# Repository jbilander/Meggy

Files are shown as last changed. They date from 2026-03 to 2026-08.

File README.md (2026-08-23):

# Meggy
A 1MB USB-programmable Kickstart ROM board for Amiga computers with a 42-pin ROM socket (A500+, A600). With a small modification also works in machines with a 40-pin ROM socket such as the A500 rev 6A and B2000.

***

<a href="images/Meggy_revC_pic1.png">
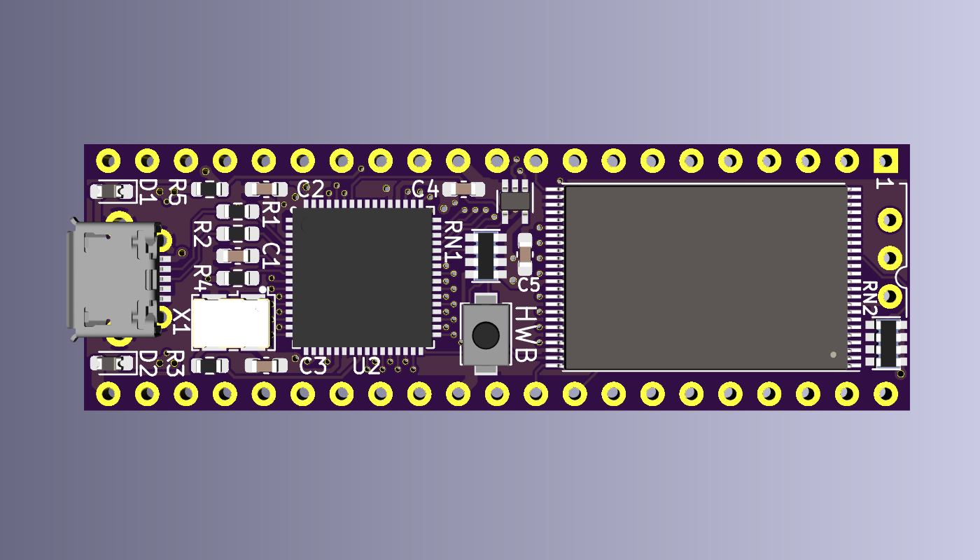
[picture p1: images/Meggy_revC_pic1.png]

</a>
<br />
<a href="images/Meggy_revC_pic2.png">
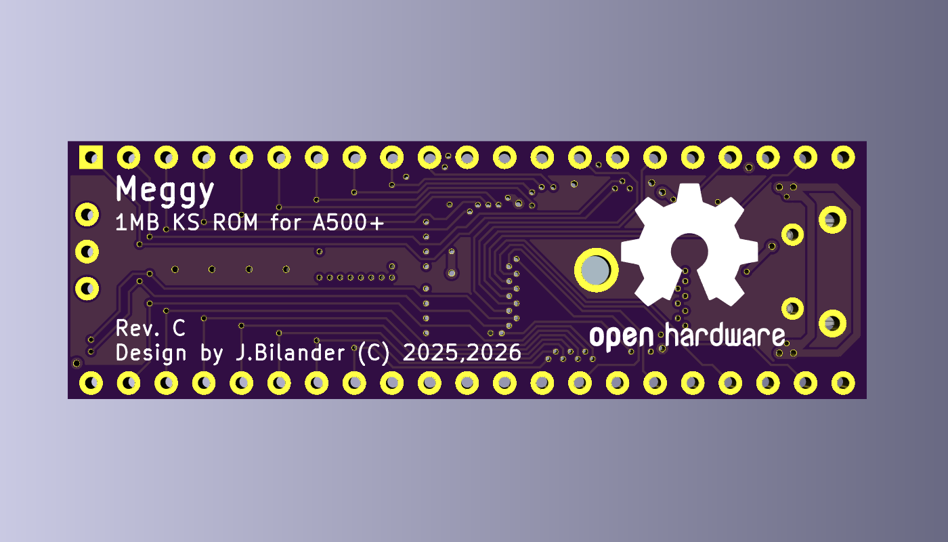
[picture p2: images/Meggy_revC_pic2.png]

</a>
<br />
<a href="images/Meggy_revC_pic3.jpg">
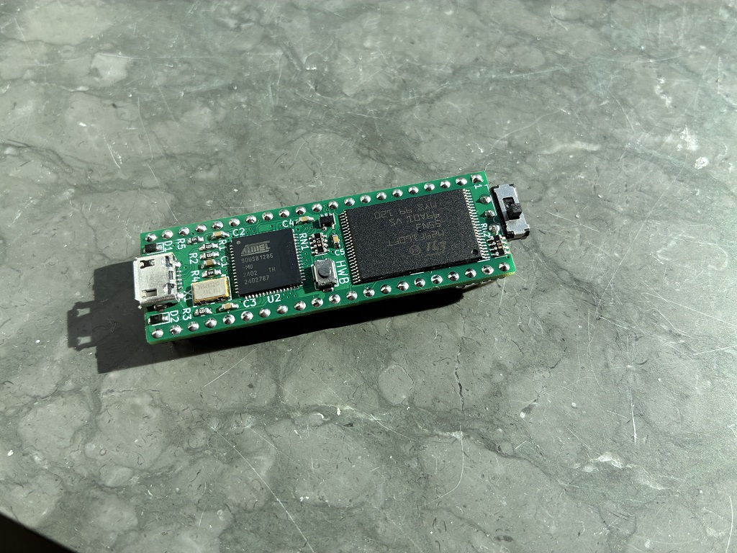
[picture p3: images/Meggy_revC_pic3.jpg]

</a>
<br />
<a href="images/Meggy_revC_pic4.jpg">
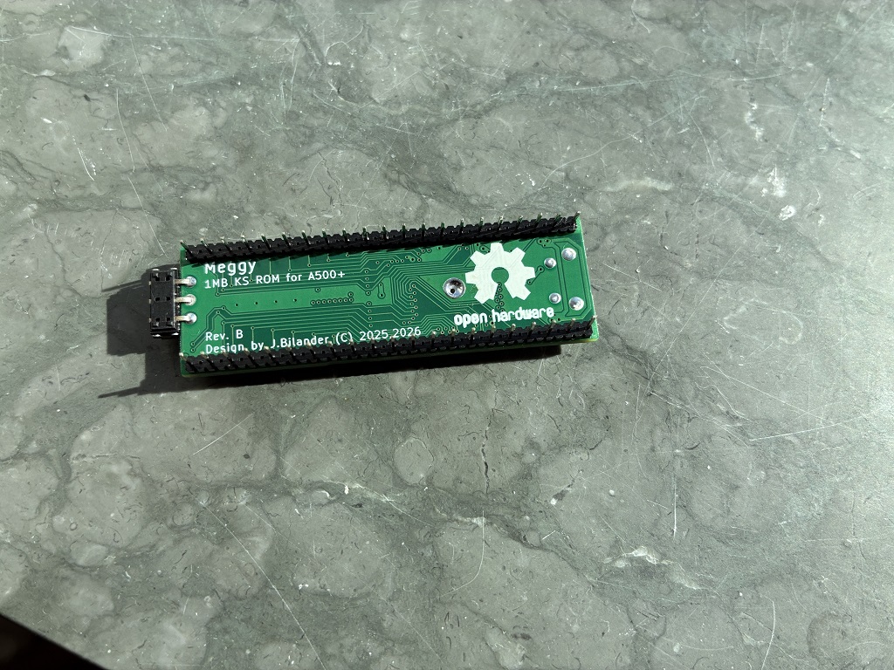
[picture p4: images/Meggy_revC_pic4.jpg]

</a>
<br />
<a href="images/Meggy_revC_installed_in_A500_plus.jpg">
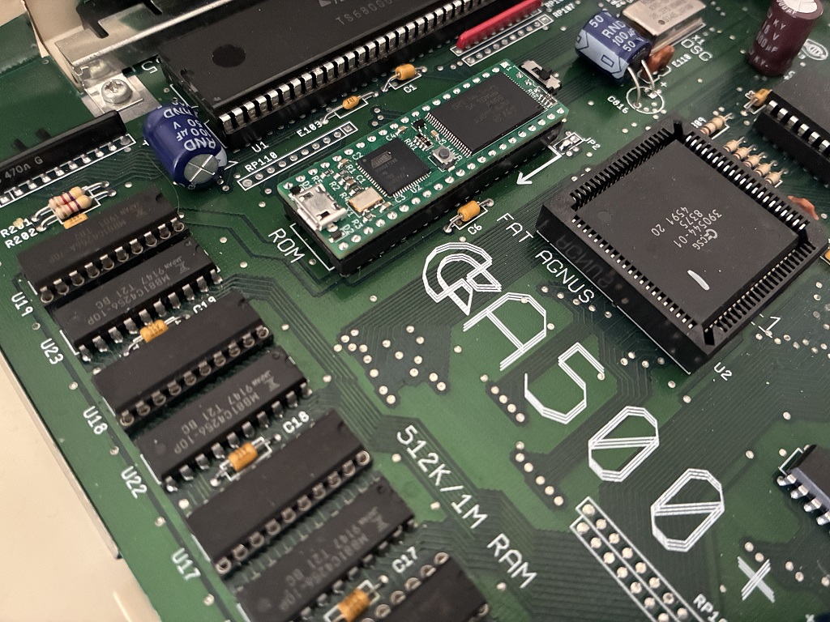
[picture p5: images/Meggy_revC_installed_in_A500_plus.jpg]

</a>
<br />

***

# Bill of Materials — Meggy Rev C

| Ref | Qty | Value | Description | Package | Notes | Mouser |
|-----|-----|---|---|---|---|---|
| U1 | 2 | — | Pin strip 1×21, 2.54mm pitch, 0.4mm square pins | — | <span title="Cut from 1×50 1.27mm pitch strip, remove every other pin to give 2.54mm pitch. Fits Amiga dual-wipe socket better than standard 0.47mm turned pins.">Pin strip info...</span> | [AliExpress example](https://www.aliexpress.com/item/4000979931385.html) |
| U2 | 1 | AT90USB1286-MU | AVR USB microcontroller | QFN-64 | | [556-AT90USB1286-MU](https://www.mouser.com/ProductDetail/556-AT90USB1286-MU) |
| U3 | 1 | M29F160FT55N3E2 | 2MB NOR Flash (top-boot) | TSOP-48 | | [913-M29F160FT55N3E2](https://www.mouser.com/ProductDetail/913-M29F160FT55N3E2) |
| U4 | 1 | 74AHCT1G126GW | Single tristate buffer | SC-70-5 / SOT-353 | <span title="Isolates Gary's /OE signal from the flash chip during USB programming. 10k pull-up on EN keeps buffer enabled by default even with no firmware loaded.">OE isolation...</span> | [771-AHCT1G126GW125](https://www.mouser.com/ProductDetail/771-AHCT1G126GW125) |
| D1, D2 | 2 | CDBU0520 | Schottky diode 0.5A 20V | SOD-523F / 0603 | <span title="Diode-OR between VBUS (USB 5V) and VCC (Amiga 5V). Prevents backfeed between the two supplies. Higher voltage wins.">Power OR...</span> | [750-CDBU0520](https://www.mouser.com/ProductDetail/750-CDBU0520) |
| X1 | 1 | 16 MHz | Crystal oscillator SG5032CCN 16.000000M-HJGA3 | 5×3.2mm SMD | | [732-5032CC16.0HJGA3](https://www.mouser.com/ProductDetail/732-5032CC16.0HJGA3) |
| SW1 | 1 | — | Sunrom Tactile Switch SMD | 3×4×2mm | <span title="Hold HWB button and run --avr-reset to enter DFU bootloader mode for firmware programming.">HWB / DFU entry...</span> | [AliExpress example](https://www.aliexpress.com/item/32855171871.html) |
| J1 | 1 | 10118194-0001LF | Micro USB-B connector, Amphenol FCI, 5-pin | SMD | | [649-10118194-0001LF](https://www.mouser.com/ProductDetail/649-10118194-0001LF) |
| J2 | 1 | MSK12D19 SMD | SMD slide switch, 3-pin, 2.5mm pitch | SMD | <span title="Flash A19 select — open = slot 1 (pull-up), shorted to GND = slot 0. Pins bent to right angle for flush mounting. Alternatively a 3-pin 2.54mm right-angle pin header with external toggle switch.">Flash A19 slot select...</span> | [AliExpress example](https://www.aliexpress.com/item/1005006482584650.html) |
| RN1, RN2 | 2 | 10k | Resistor network 4×10kΩ isolated | 0603×4 (1206) | CAY16-103J4LF | [652-CAY16-103J4LF](https://www.mouser.com/ProductDetail/652-CAY16-103J4LF) |
| R1, R2 | 2 | 22Ω | CR0603-FX-22R0ELF — USB D+/D− series resistors | 0603 | | [652-CR0603FX-22R0ELF](https://www.mouser.com/ProductDetail/652-CR0603FX-22R0ELF) |
| R3 | 1 | 22Ω | CR0603-FX-22R0ELF — Clock series termination | 0603 | | [652-CR0603FX-22R0ELF](https://www.mouser.com/ProductDetail/652-CR0603FX-22R0ELF) |
| R4 | 1 | 100Ω | CR0603-FX-1000ELF — VBUS detection | 0603 | <span title="Series resistor between VBUS_5V and AVR VBUS pin 8 for USB bus voltage detection.">VBUS detect...</span> | [652-CR0603FX-1000ELF](https://www.mouser.com/ProductDetail/652-CR0603FX-1000ELF) |
| R5 | 1 | 10kΩ | CR0603-FX-1002ELF — OE_BUF_EN pull-up | 0603 | <span title="Pull-up to VCC on PE4 (OE_BUF_EN). Keeps the 74AHCT1G126GW buffer enabled by default so Gary controls /OE even with no firmware loaded.">OE_BUF_EN pull-up...</span> | [652-CR0603FX-1002ELF](https://www.mouser.com/ProductDetail/652-CR0603FX-1002ELF) |
| C1 | 1 | 1µF | CL10B105KA8NNND | 0603 | <span title="UCAP filter capacitor on AVR pin 7. Required for the AT90USB1286 internal USB voltage regulator.">UCAP filter...</span> | [187-CL10B105KA8NNND](https://www.mouser.com/ProductDetail/187-CL10B105KA8NNND) |
| C2, C3, C4, C5 | 4 | 100nF | CL10B104KA8NNNC — Bypass decoupling | 0603 | <span title="Bypass decoupling capacitors. Place as close as possible to the VCC pins of U2, U3 and U4.">Bypass decoupling...</span> | [187-CL10B104KA8NNNC](https://www.mouser.com/ProductDetail/187-CL10B104KA8NNNC) |

## Key ICs

**AT90USB1286-MU** — Atmel/Microchip AVR, 128KB flash, native full-speed USB, QFN-64. Runs the Meggy firmware and provides USB bulk transfer for flash programming. DFU bootloader in hardware boot section (no external programmer needed after initial setup).

**M29F160FT55N3E2** — Micron/ST 16Mbit (2MB) NOR flash, top-boot, 55ns, 5V, x16. Stores two 1MB Kickstart image slots selectable via the A19 switch. [Datasheet](https://www.mouser.com/datasheet/3/893/1/M29FxxFT_FB.pdf)

**74AHCT1G126GW** — Single buffer with tristate output (active-high enable). Isolates Gary's /OE signal from the flash chip during USB programming operations. 10k pull-up on EN ensures the buffer is enabled (Amiga in control) by default even with no firmware loaded.

**CDBU0520** — Comchip 0.5A 20V Schottky diode, SOD-523F (0603 footprint). Two used for power OR between VBUS (USB) and VCC (Amiga). Prevents backfeed between the two supplies.

## Power

The board can be powered from either:
- **VBUS** (USB 5V) — when connected to a PC for programming
- **VCC** (Amiga 5V) — when installed in the Amiga

D1 and D2 form a diode-OR, allowing both supplies to coexist safely. The higher voltage wins. Schottky forward drop is approximately 150–200mV at typical operating currents.

***

# Assembly Notes

## Pin Headers (U1)

The two 1×21 pin headers that plug into the Amiga ROM socket are made from standard **1.27 mm pitch pin strips** with every other pin used, giving 21 pins per row at 2.54 mm pitch.

The reason for starting with 1.27 mm strips rather than conventional 2.54 mm strips is pin geometry: 1.27 mm strips have **0.4 mm square pins**, which seat noticeably better in Amiga dual-wipe sockets than the turned (round) pins found on 2.54 mm strips. Turned pins are typically ~0.47 mm in diameter and can spread the socket contacts over time, whereas the slimmer square pins make clean contact without stressing the socket.

### Preparation

Start with two 1.27 mm pitch pin strips, each at least 42 pins long. Using pliers or a similar tool, push every other pin down flush with the top face of the plastic guard — these are the pins that will not be soldered. The result is a strip that alternates between full-length protruding pins and pins that sit flush inside the guard.

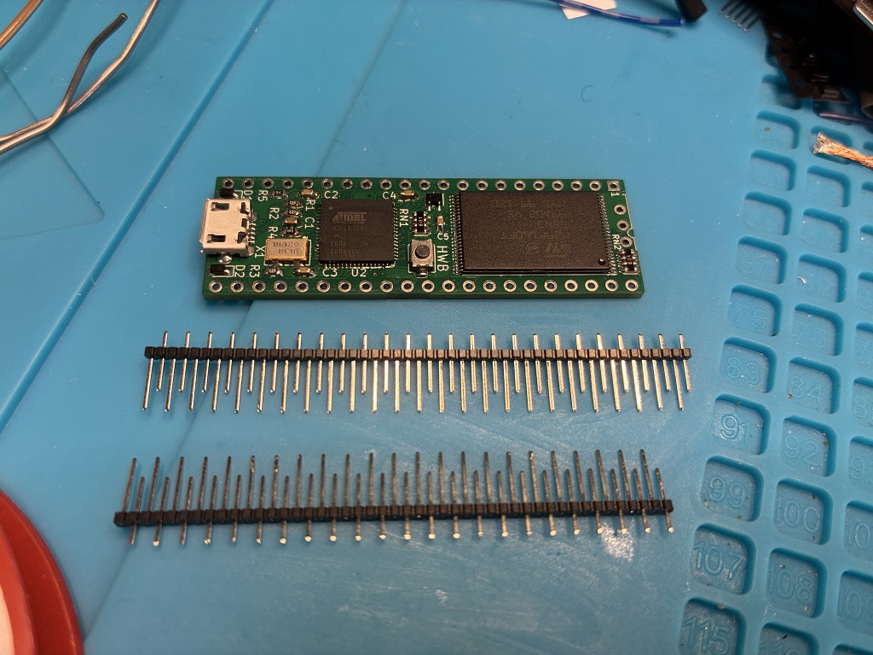
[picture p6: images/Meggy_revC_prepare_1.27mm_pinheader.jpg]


### Self-aligning soldering technique

Place both prepared strips on the work surface with the **plastic guard facing down** and the full-length pins pointing upward. Set the Meggy PCB flat on top so that it rests on the two strips — the full-length pins pass up through the PCB holes from below while the board's own weight holds everything in place.

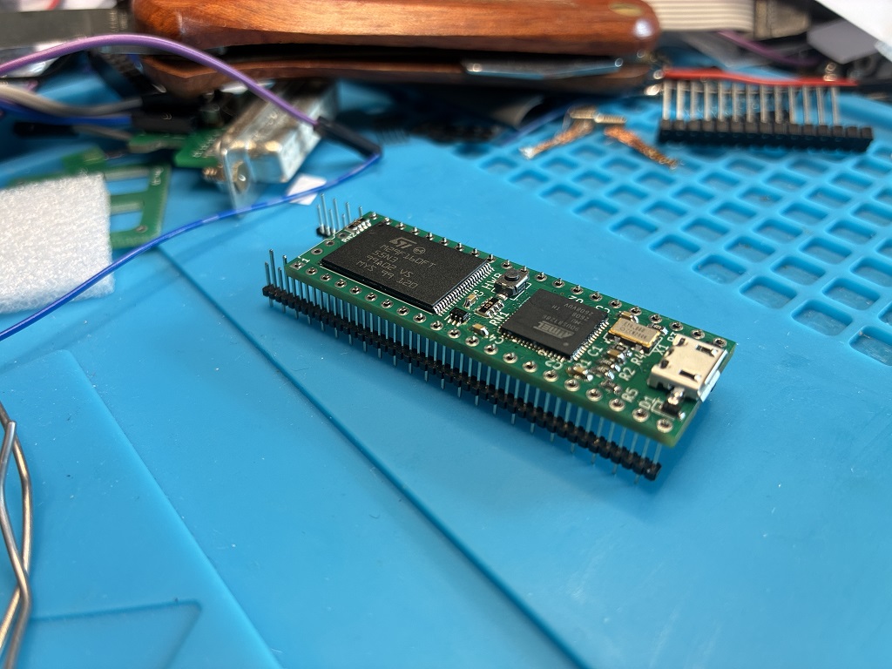
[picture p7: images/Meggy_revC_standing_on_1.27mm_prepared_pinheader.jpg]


Align both strips as straight as possible along the PCB edges, then **tack one corner of each strip** to hold them in position.

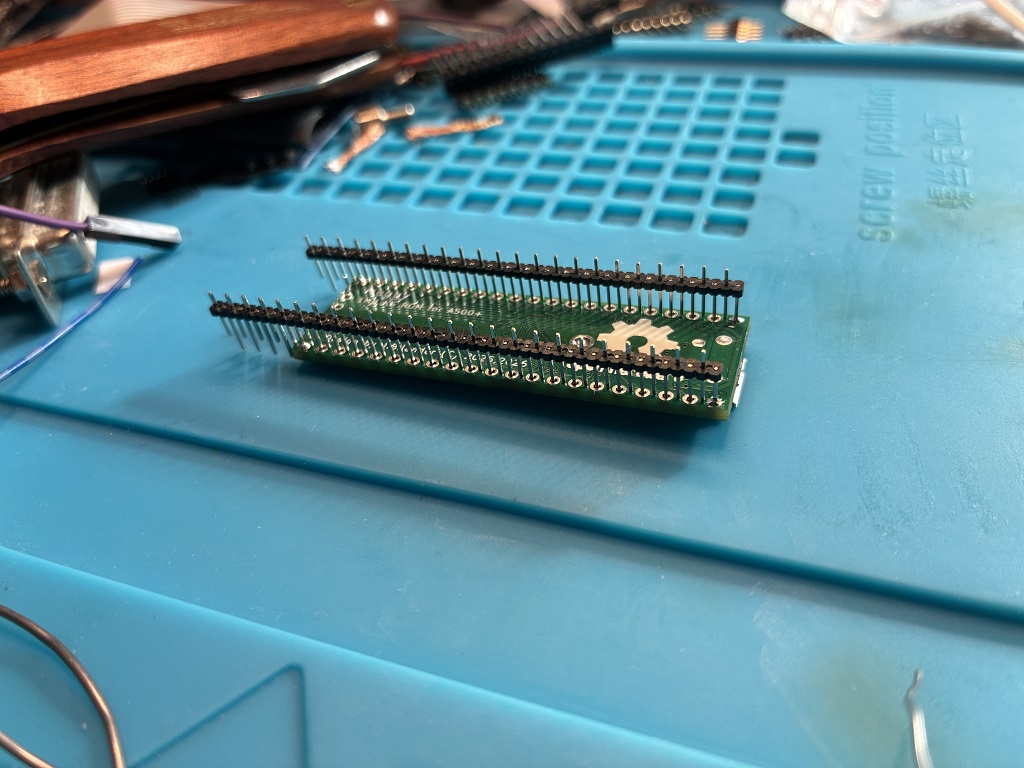
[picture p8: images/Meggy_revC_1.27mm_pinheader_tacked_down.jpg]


At this stage it is still easy to correct misalignment — reflow a tacked corner with the iron, nudge the strip with your finger, and re-tack. Check that the pins protrude consistently above the PCB along the full length of each strip before proceeding. When both strips are correctly aligned, solder all remaining pins from the top side.

After soldering, the underside of the board looks like this:

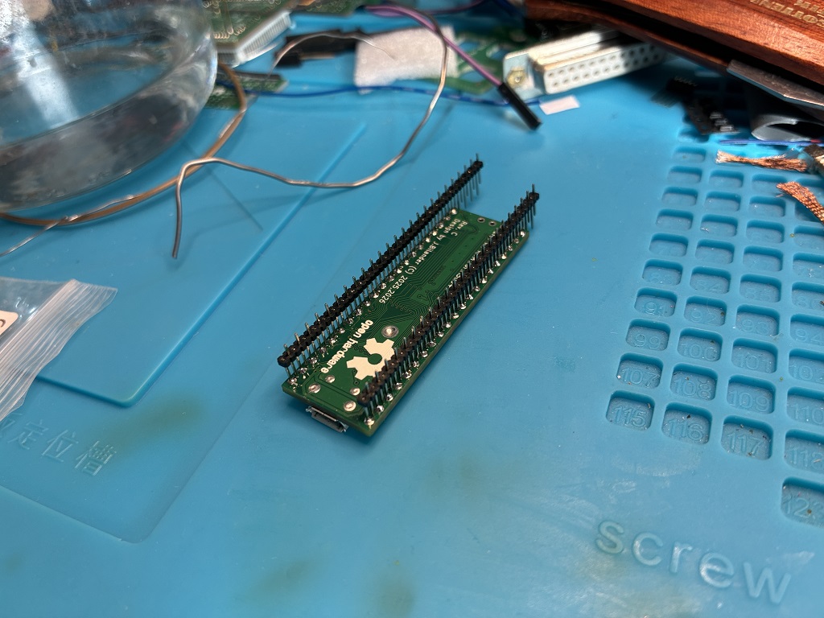
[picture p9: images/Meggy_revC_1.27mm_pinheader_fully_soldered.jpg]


### Removing the plastic guard

With all pins soldered, grip the plastic guard firmly and pull it straight down away from the PCB. The guard separates cleanly by hand — the alternating flush pins are retained inside it and come away with it, leaving only the soldered pins.

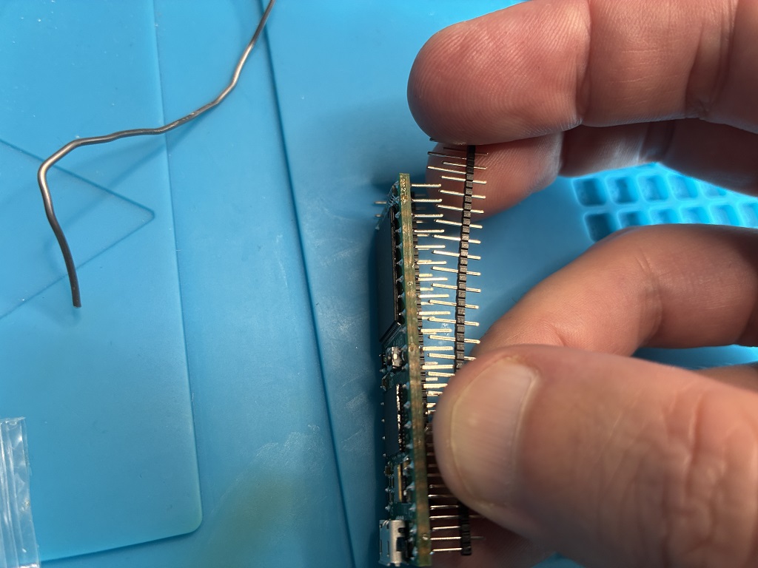
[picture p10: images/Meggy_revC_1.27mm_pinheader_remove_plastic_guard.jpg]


The finished board has two neat rows of evenly spaced pins with no plastic guard to limit insertion depth, allowing Meggy to seat fully into any socket.

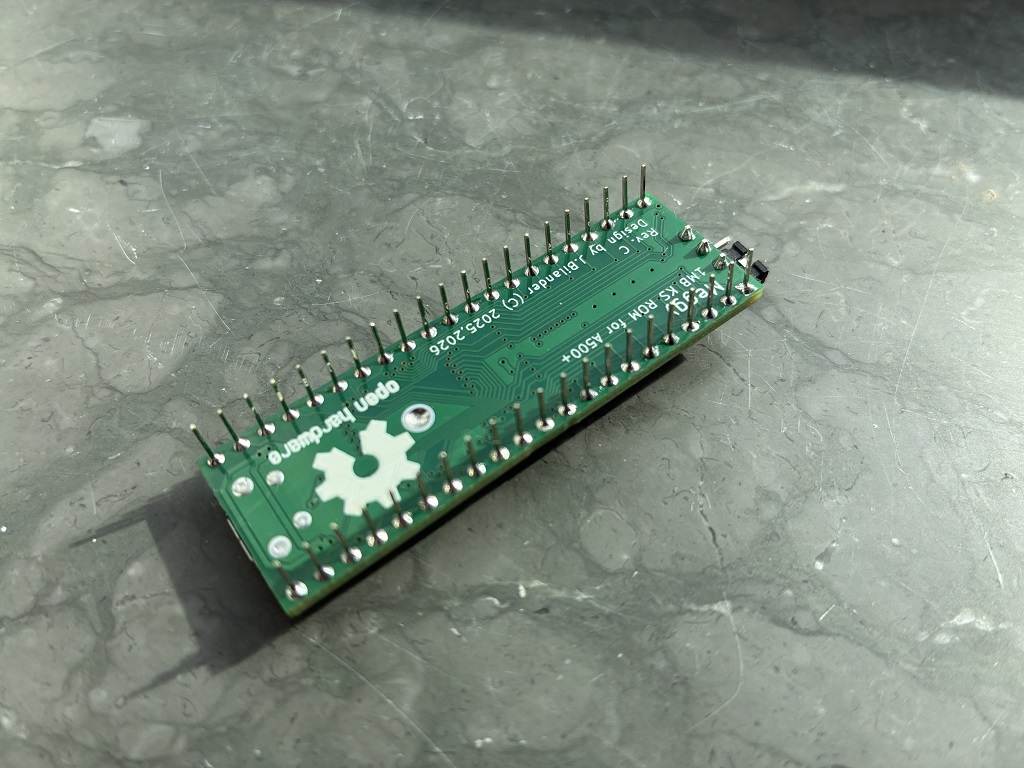
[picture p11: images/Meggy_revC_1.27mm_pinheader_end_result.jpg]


## J2 Slide Switch (MSK12D19) — Bending and Soldering

The MSK12D19 is an SMD slide switch soldered flat on the PCB with its pins bent over and soldered from the top side. To change the Kickstart slot the Amiga needs to be opened. Alternatively J2 can be fitted with a 3-pin 2.54mm right-angle pin header and wired to an external toggle switch mounted somewhere accessible on the Amiga case.

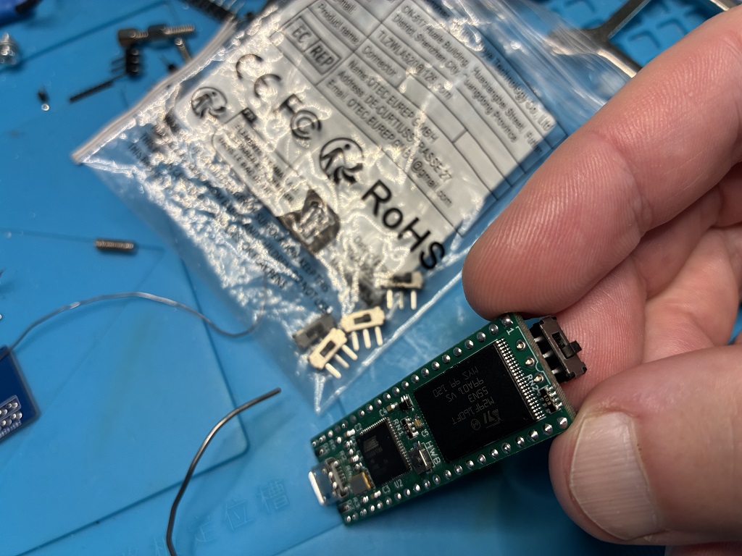
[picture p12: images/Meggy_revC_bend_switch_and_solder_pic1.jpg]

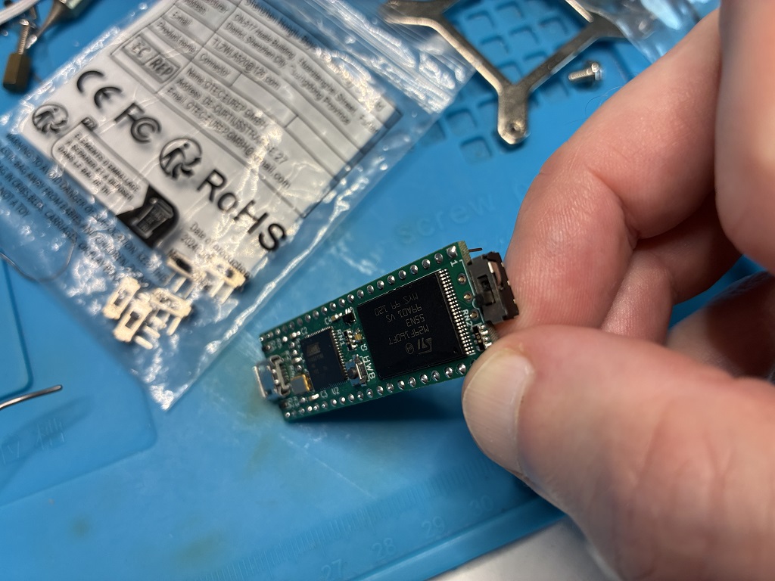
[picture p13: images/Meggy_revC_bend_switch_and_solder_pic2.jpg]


**Steps:**
1. Place the switch into the J2 footprint so the three pins protrude slightly through the top side of the PCB.
2. With your fingers, bend all three pins over flat against the top surface so the switch body ends up level with the board.
3. Apply flux and solder the three pins from the top side with a regular soldering iron.

## AVR Exposed Pad and USB Connector — Soldering Technique

The AT90USB1286-MU QFN-64 has a large exposed thermal pad on the underside that must be soldered to the GND pour for reliable operation. The Micro USB connector also has through-hole anchor pins. Both benefit from using a desoldering station with good thermal mass — a ZD915 or similar works well for this.

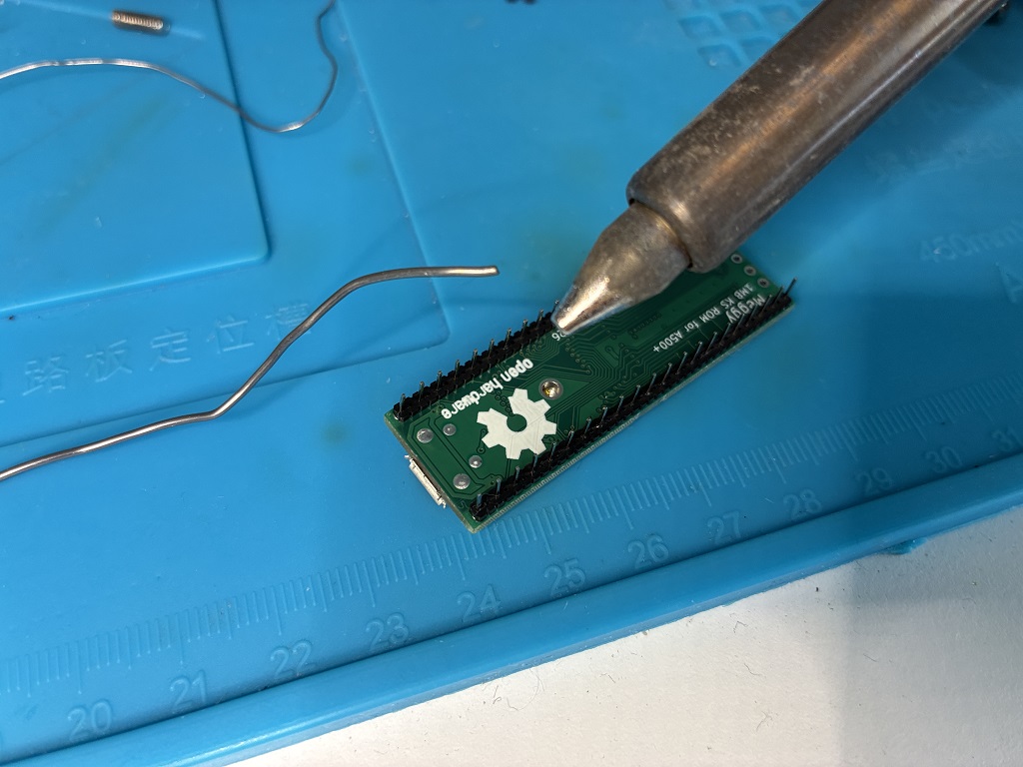
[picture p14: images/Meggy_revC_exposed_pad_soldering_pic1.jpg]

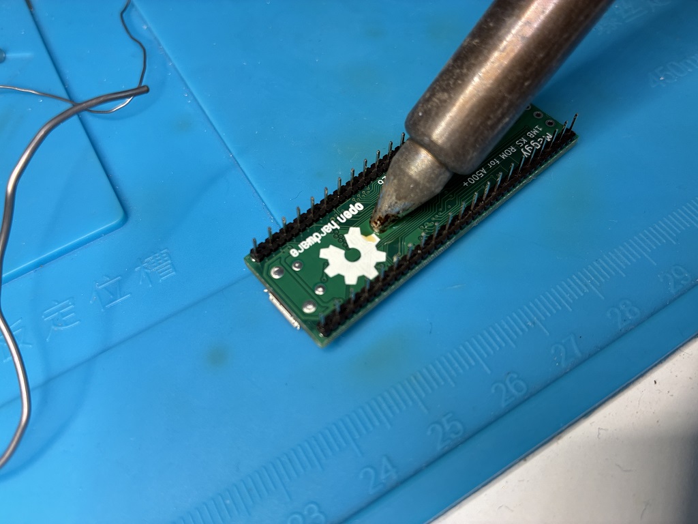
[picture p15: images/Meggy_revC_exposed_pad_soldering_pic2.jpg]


**AVR exposed pad:**
1. Apply flux into the PCB via hole that sits directly under the exposed pad.
2. Place the desoldering nozzle against the hole from the underside and feed solder wire into the nozzle, holding for 3–4 seconds. The thermal mass of the station heats the via quickly and the solder wicks up through the hole making solid contact with the exposed pad above.

**USB connector through-hole anchor pins:**
1. Apply flux on both sides of the PCB at each anchor pin hole.
2. Solder from one side — applying flux to the opposite side encourages a clean bleed-through joint, giving a solid mechanical connection.

***

# Windows Setup

Meggy uses two distinct USB personalities:

| Mode | USB ID | When active | Driver needed |
|---|---|---|---|
| **DFU bootloader** | 03EB:2FFB | No firmware, or HWB held during power-up | libusb-win32 (via Zadig) |
| **Flash programmer** | 03EB:2044 | Normal firmware operation | WinUSB (via Zadig) |

Both drivers are installed with [Zadig](https://zadig.akeo.ie). The steps below cover the full setup from a fresh Windows machine.

## Prerequisites

- **Arduino IDE 1.8.x** — provides `avrdude.exe` used by `flash.bat` to program the AVR firmware. Tested with Arduino IDE 1.8.16. Newer versions of Arduino IDE (2.x) install avrdude in a different location and may require editing the `AVR_PATH` variable in `build.bat` and `flash.bat`. Download from [arduino.cc](https://www.arduino.cc/en/software).
- **Python 3.x** — required for `meggy_flash.py` (see Step 1 below).

---

## Step 1 — Install Python

Download Python 3.x (64-bit) from [python.org](https://www.python.org/downloads/) and run the installer.

**Important:** tick **"Add python.exe to PATH"** before clicking Install Now.

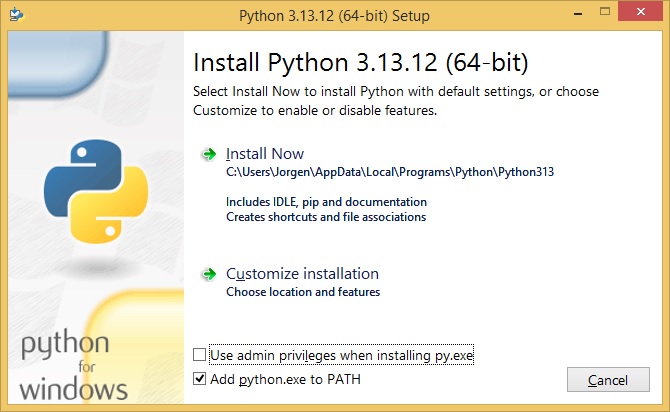
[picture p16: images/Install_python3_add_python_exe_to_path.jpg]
Install Python — tick Add python.exe to PATH


---

## Step 2 — Install PyUSB

Open a Command Prompt and run:

```
pip install pyusb
```

If you run `meggy_flash.py` before installing PyUSB you will see the reminder message shown below — just run the pip command and try again.

PyUSB not found — pip install pyusb

---

## Step 3 — Install libusb-1.0.dll

PyUSB on Windows requires `libusb-1.0.dll` to be present. Download the latest libusb release from [libusb.info](https://libusb.info), open the archive with 7-Zip or similar, and copy `libusb-1.0.dll` from the `VS2015\MS64\dll\` folder into `C:\Windows\System32`.

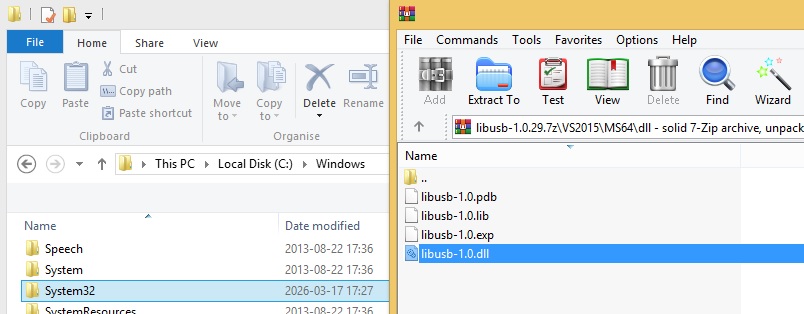
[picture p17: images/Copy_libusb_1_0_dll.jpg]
Copy libusb-1.0.dll to C:\Windows\System32


---

## Step 4 — Install Zadig

Download [Zadig](https://zadig.akeo.ie) (a single portable `.exe`, no installation required) and save it somewhere convenient.

zadig-2.9.exe in Downloads folder

---

## Step 5 — Install the DFU driver (libusb-win32)

This driver is used when Meggy is in DFU bootloader mode for **firmware** programming.

**Put Meggy into DFU mode:**

A freshly soldered board with no firmware loaded will enter DFU mode automatically on power-up — just plug in the USB cable and the device enumerates as **AT90USB128 DFU** without any button press needed.

If firmware is already installed, hold the HWB button and run `python meggy_flash.py --avr-reset` (see the Firmware Programming section below).

Windows will detect a new device. Without the driver it appears as **AT90USB128 DFU** under *Other devices* in Device Manager with a warning icon.

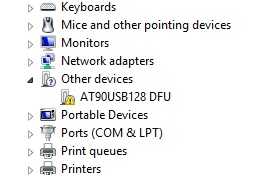
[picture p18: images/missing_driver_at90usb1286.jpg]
AT90USB128 DFU listed as unknown device


Open Zadig. The device **AT90USB128 DFU** (USB ID `03EB 2FFB`) should appear in the dropdown. Make sure the target driver on the right is set to **libusb-win32**, then click **Install Driver**.

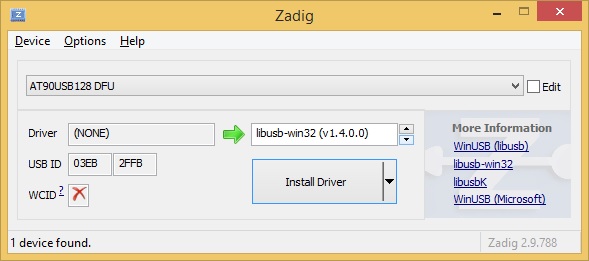
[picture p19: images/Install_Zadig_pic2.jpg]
Zadig — installing driver progress bar


Zadig installs the driver (this takes a few seconds).

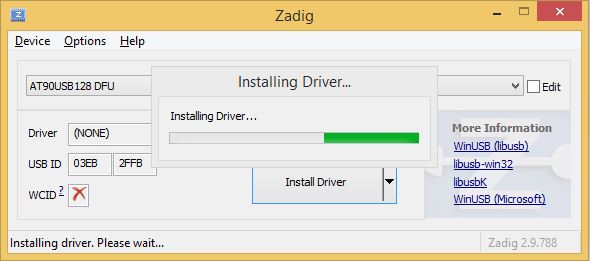
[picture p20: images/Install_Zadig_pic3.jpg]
Zadig — driver installed successfully


When complete, Zadig reports **"The driver was installed successfully."**

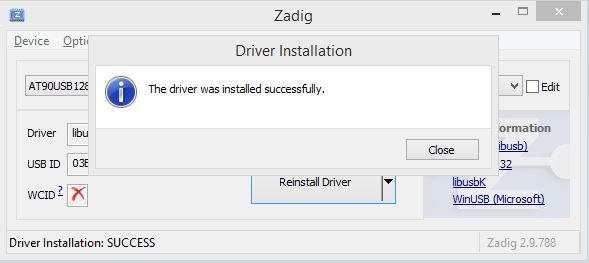
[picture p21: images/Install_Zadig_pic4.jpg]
Device Manager — AT90USB128 DFU under libusb-win32 devices


Device Manager now shows **AT90USB128 DFU** under *libusb-win32 devices* — no warning icon.

Zadig — select libusb-win32 for AT90USB128 DFU

---

## Step 6 — Install the Flash Programmer driver (WinUSB)

This driver is used during normal operation when Meggy presents itself as the **Meggy Flash Programmer** for **NOR flash** programming.

Unplug Meggy and plug it back in without holding HWB so it boots into normal firmware mode. Windows detects it as **Meggy Flash Programmer** under *Other devices*. If you try to install the driver via Windows Update or Device Manager directly, Windows will refuse because the INF lacks a digital signature.

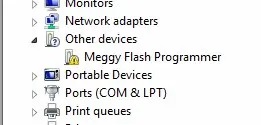
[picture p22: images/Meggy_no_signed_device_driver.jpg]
Meggy Flash Programmer — no signed driver error

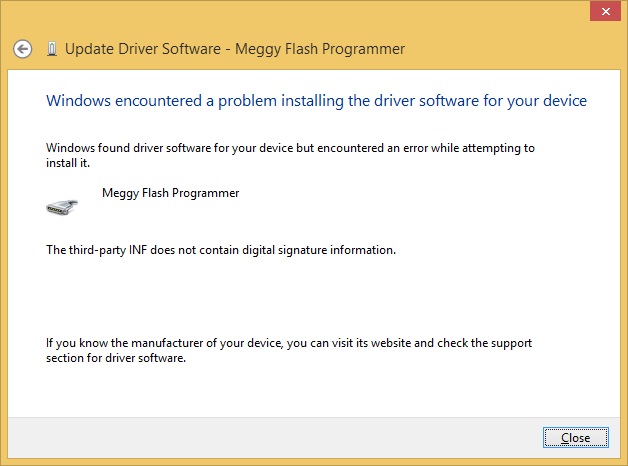
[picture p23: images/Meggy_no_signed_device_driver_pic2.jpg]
Windows driver signature error dialog


Use Zadig instead. Select **Meggy Flash Programmer** (USB ID `03EB 2044`) from the dropdown and confirm the target driver on the right is **WinUSB**, then click **Install Driver**.

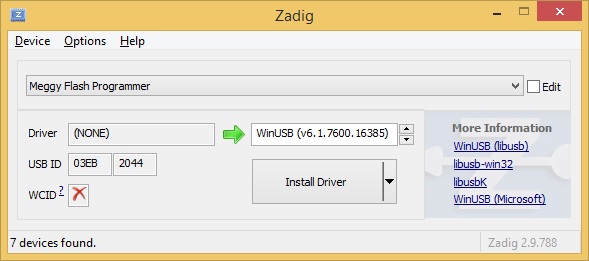
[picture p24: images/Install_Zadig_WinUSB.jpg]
Zadig — select WinUSB for Meggy Flash Programmer


Zadig installs the driver and reports success.

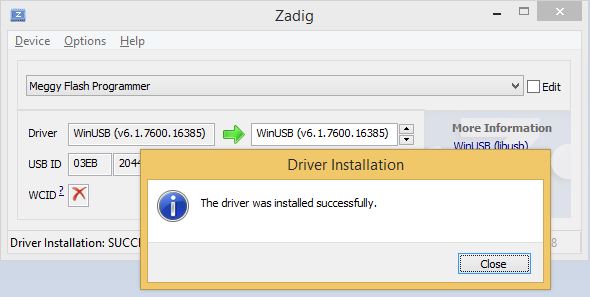
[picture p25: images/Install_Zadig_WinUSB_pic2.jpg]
Zadig — WinUSB driver installed successfully


Device Manager now shows **Meggy Flash Programmer** under *Universal Serial Bus devices*.

Device Manager — Meggy Flash Programmer under Universal Serial Bus devices

Both drivers are now in place and setup is complete.

***

# Firmware Programming

The AT90USB1286 ships with a USB DFU bootloader burned into the hardware boot section. This bootloader cannot be erased, so no external programmer is ever required after the chip is soldered.

## Entering DFU Mode

A freshly soldered board with no firmware loaded will enter DFU mode automatically on power-up — just plug in USB and it enumerates as **AT90USB128 DFU** (USB ID `03EB:2FFB`) without any button press needed.

If firmware is already installed:

**Preferred method** (firmware running):
1. Hold the HWB button.
2. Run `python meggy_flash.py --avr-reset`
3. Release HWB once avrdude connects.

The `--avr-reset` command triggers a hardware reset via the PE5→RESET connection, which causes the bootloader to check HWB and enter DFU mode. This is the only way to enter DFU mode when firmware is already running on Rev C.

## Building the Firmware

From the `firmware/` folder, run:

```bat
build.bat
```

This compiles the firmware and produces `meggy_firmware.hex`. LUFA must be cloned into the `firmware/LUFA/` subfolder first:

```bat
cd firmware
git clone https://github.com/abcminiuser/lufa LUFA
```

## Flashing the Firmware (Windows)

From the `firmware/` folder, run:

```bat
flash.bat
```

This calls `avrdude` with the `flip1` programmer protocol targeting the AT90USB1286 DFU bootloader and handles firmware upload and verification automatically. Some harmless warnings about fuse bits not being accessible via FLIP are expected and can be ignored.

After flashing, power cycle the board to return to normal firmware mode:
- **Standalone:** unplug and replug USB.
- **Installed in Amiga:** disconnect USB and Amiga power, then reconnect.

## Flashing the Firmware (Linux / macOS)

Install `dfu-programmer` via your package manager, then:

```sh
dfu-programmer at90usb1286 erase
dfu-programmer at90usb1286 flash meggy_firmware.hex
dfu-programmer at90usb1286 start
```

The `start` command reboots the AVR automatically into firmware mode. Meggy will enumerate as **Meggy Flash Programmer** (USB ID `03EB:2044`), ready for NOR flash programming.

***

# NOR Flash Programming

With the firmware running and the WinUSB driver installed, use `meggy_flash.py` from the `firmware/` folder to read and write the M29F160 NOR flash over USB.

**Important:** set the J2 switch to the desired slot **before** running any programming commands. The physical switch position determines which 1MB half of the flash chip is accessed — the software always programs whichever slot the switch currently selects.

**Power and bus contention note:** the safest way to program Meggy is standalone — removed from the Amiga socket and powered from USB only. This avoids both power and bus contention issues entirely.

Programming while installed in the Amiga with the Amiga powered off would be equally convenient, but unfortunately does not work reliably. The unpowered chips on the motherboard (CPU, Gary, RAM) draw current through their protection diodes from Meggy's bus lines, dragging down the supply voltage during programming and causing timeouts at around 12% through the image.

With the Amiga powered on, programming works reliably in practice, but there is a theoretical bus contention risk: the address and data lines are shared directly between the AVR and the Amiga bus, and the CPU may drive the same lines simultaneously during any bus cycle. The /OE isolation provided by U4 (74AHCT1G126GW) prevents Gary from asserting /OE on the flash, so the flash will not drive data lines in response to Amiga read cycles — if the CPU attempts a ROM read it simply reads floating lines and stalls or crashes harmlessly. The flash being in read mode between programming operations is the safer state; the contention risk is highest during the brief /WE pulse when the AVR actively drives data lines. In practice the contention window is very brief and programming completes without errors, but for critical or repeated programming operations removing the board first is the cleanest approach.

## Quick-start

```sh
# Identify the device and flash chip
python meggy_flash.py --identify

# Write a Kickstart image (set J2 switch to desired slot first)
python meggy_flash.py --write kick31.rom

# Write a Kickstart image with 16-bit byte-swap applied (for unswapped ROM files)
python meggy_flash.py --write kick31.rom --swap

# Read back the current slot for verification
python meggy_flash.py --read-slot readback.bin

# Verify flash contents against a ROM file
python meggy_flash.py --verify kick31.rom

# Erase the current slot
python meggy_flash.py --erase

# Reset the AVR into DFU mode (hold HWB button while executing this command)
python meggy_flash.py --avr-reset
```

***

# Using Meggy in a 40-pin ROM Socket (A500 rev 6A, A2000)

Meggy is designed for the 42-pin ROM socket found in the A500+ and A600. With a small modification it also works in machines with a 40-pin ROM socket such as the A500 rev 6A and A2000, which lack pin 1 (A19) and pin 42 (A20). The following has been tested on an A500 rev 6A.

## Modifications Required

**J2 slot switch — replace MSK12D19 with a pin header:**
On the A500 rev 6A the can oscillator on the motherboard sits directly below where the MSK12D19 slide switch would be, making it impossible to fit. Desolder the MSK12D19 from J2 and replace it with a standard 3-pin 2.54mm right-angle pin header. A standard 2.54mm jumper shunt can then be used to select the slot, and the right-angle header clears the can oscillator without conflict.

**Remove the plastic guards from the pin strips (if not already done):**
Single-wipe sockets have shallower contact depth than dual-wipe sockets. The plastic guard on the pin strips adds height that may prevent Meggy from seating fully into the socket. If you followed the recommended assembly method in the Pin Headers section above the guards will already have been removed as the final step of soldering — no further action is needed. If the guards are still present, grip each one firmly and pull it straight down away from the PCB; it should separate cleanly by hand, bringing the alternating unused pins with it.

**A19 jumper wire:**
The 42-pin socket has pin 1 carrying the CPU A19 signal, which selects which 512KB bank of the Kickstart the CPU is accessing. The 40-pin socket does not have this pin, so Meggy's pin 1 will hang over the edge of the socket with no connection. A short jumper wire must be soldered from Meggy's pin 1 to the A19 signal on the motherboard.

On the A500 rev 6A the A19 signal is conveniently available at solder jumper JP2 on the motherboard, which is only about 1cm from where Meggy's pin 1 overhangs the socket — making it a very short and clean connection. Alternatively A19 can be found at pin 47 of the 68000 CPU (DIP-64 package).

## Compatibility Notes

- Tested and working on A500 rev 6A with Kickstart 3.1.4 (512KB duplicated) and 1MB capitoline image
- The single-wipe socket on the A500 rev 6A gives less firm contact than a dual-wipe socket — replacing it with a good quality dual-wipe socket is recommended for long term reliability
- The 1MB capitoline extended ROM image works correctly — icon.library 45.22 and workbench.library 45.194 load from extended ROM at $E00000 even when booting an older Workbench disk

## Photos

Meggy with plastic guards still on the pin strips:

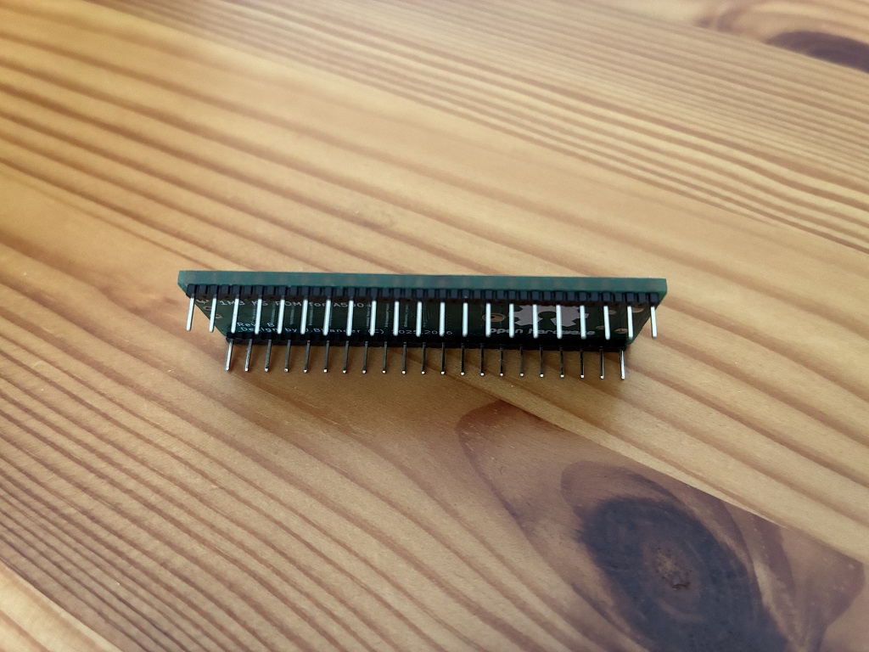
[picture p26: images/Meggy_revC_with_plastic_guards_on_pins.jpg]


Plastic guards removed and laid next to the board. Also visible: the 3-pin right-angle header fitted to J2 in place of the MSK12D19, with a standard jumper shunt for slot selection:

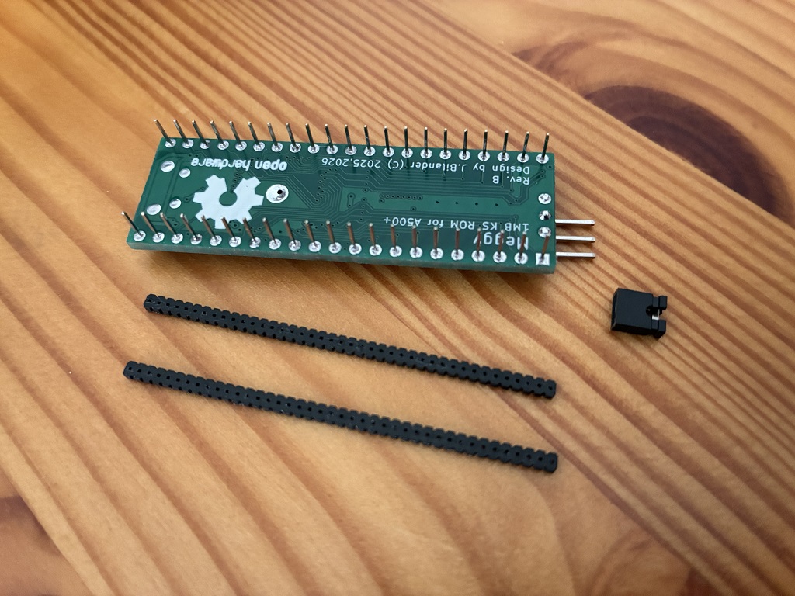
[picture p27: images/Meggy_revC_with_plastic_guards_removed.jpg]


Meggy installed in the A500 rev 6A 40-pin socket. Pin 1 hangs over the left edge of the socket with no connection yet. The can oscillator is visible to the left — this is why the MSK12D19 had to be replaced with a pin header. JP2 carrying the A19 signal is visible on the motherboard just to the left of Meggy's overhanging pin 1:

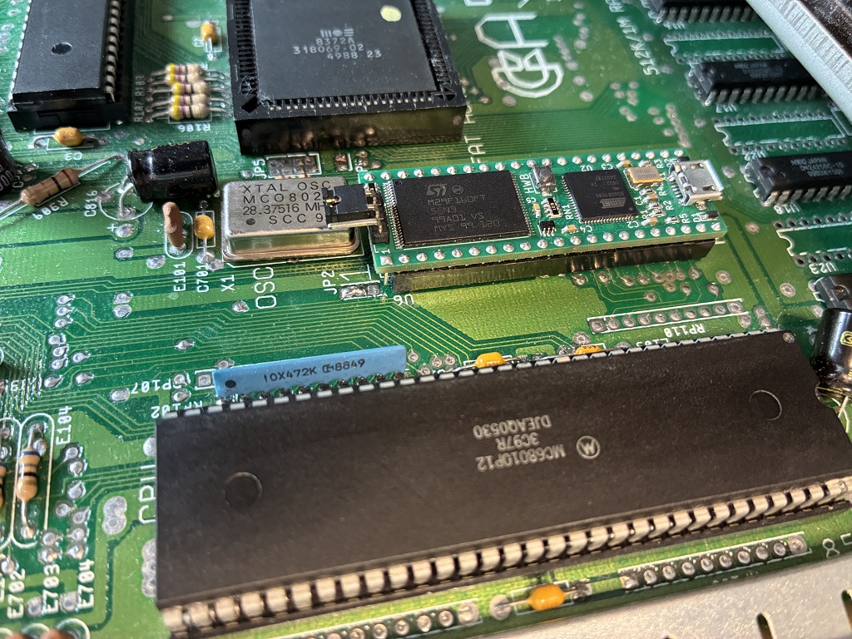
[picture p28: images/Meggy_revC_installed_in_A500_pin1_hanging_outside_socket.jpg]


Meggy installed with the A19 jumper wire connected. Yellow test clip leads run from Meggy's overhanging pin 1 to the A19 signal on the 68000 CPU. JP2 on the motherboard — visible just to the left of Meggy — provides a much neater and closer connection point for a permanent wire:

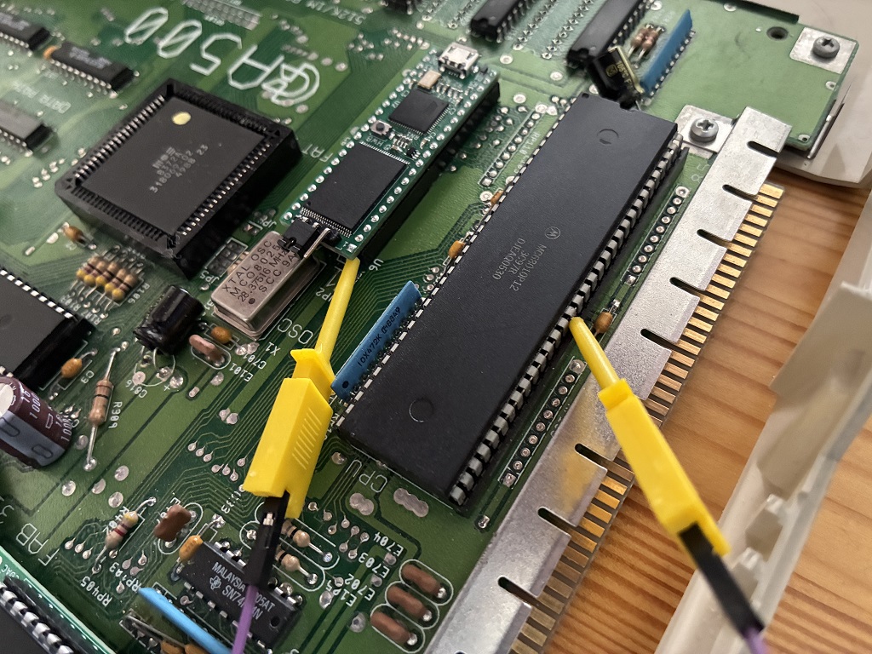
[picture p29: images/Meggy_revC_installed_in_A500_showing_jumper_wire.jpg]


DiagROM V1.2.1 running on the A500 rev 6A — CPU 68000, 1024kB chip RAM confirmed:

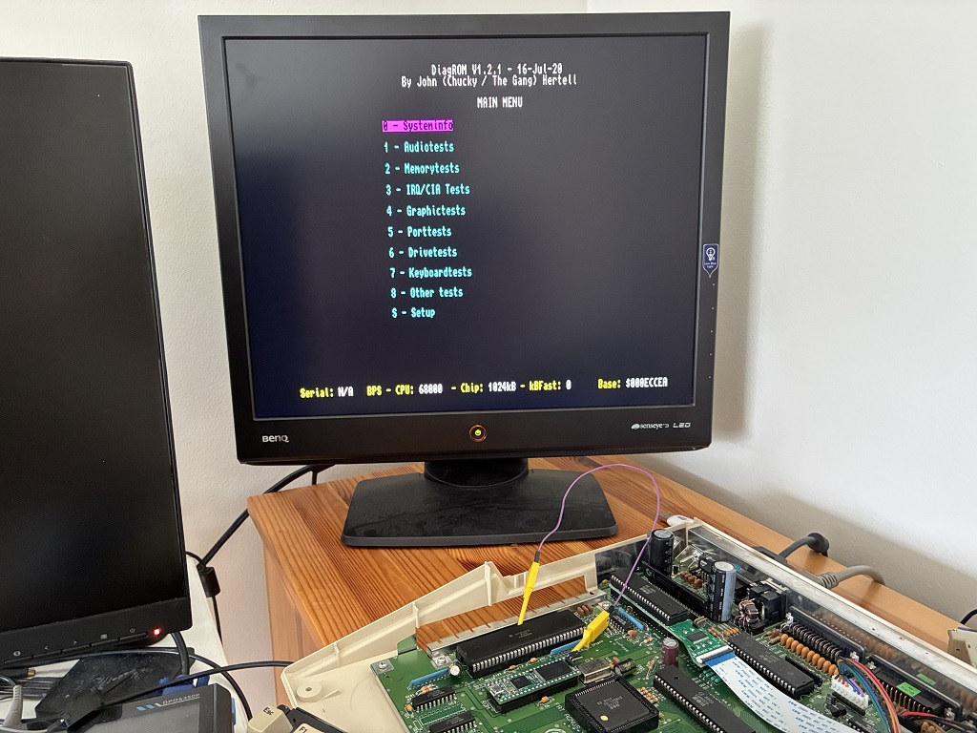
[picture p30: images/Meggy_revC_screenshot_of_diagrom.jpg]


Workbench 1.3 (34.34) booting under Kickstart 3.1.4 (46.143) on the A500 rev 6A. icon.library version 45.22 and workbench.library version 45.194 are both loading from the extended ROM at $E00000 — confirming the full 1MB capitoline image works correctly on the A500 rev 6A:

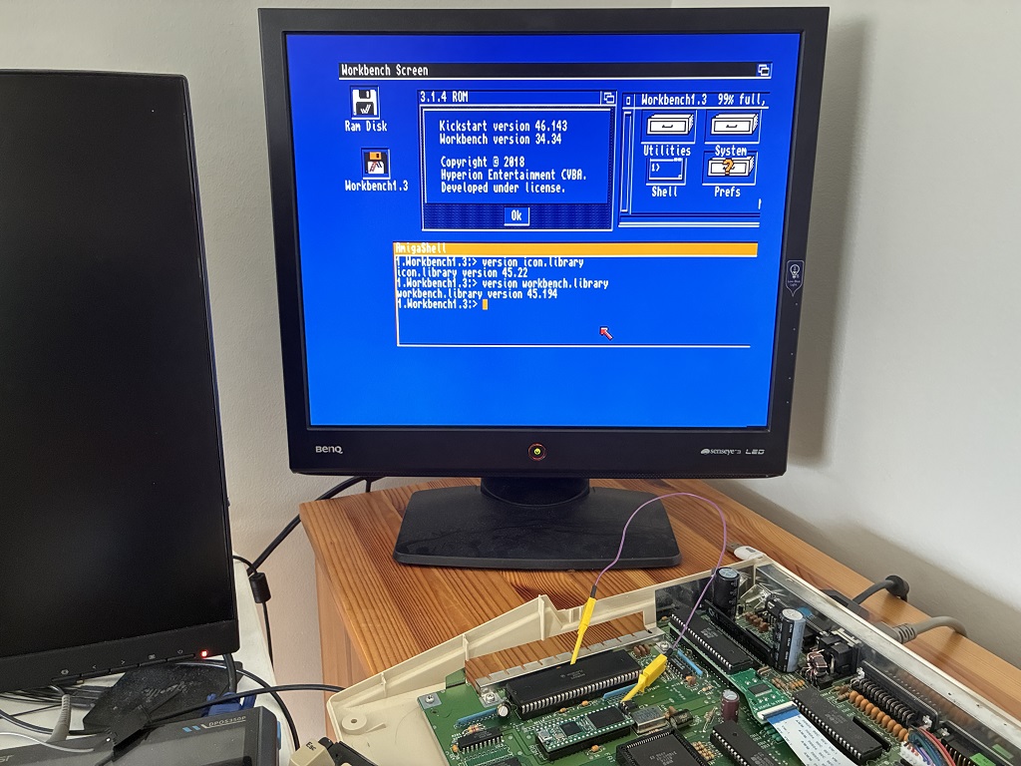
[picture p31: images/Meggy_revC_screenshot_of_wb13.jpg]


***

# Power Supply Measurements

The diode-OR power circuit was measured with a multimeter to verify correct operation. All measurements taken with Meggy Rev C installed in the Amiga. Click any image for full size.

**USB VBUS and Schottky drop — Amiga off, USB plugged:**

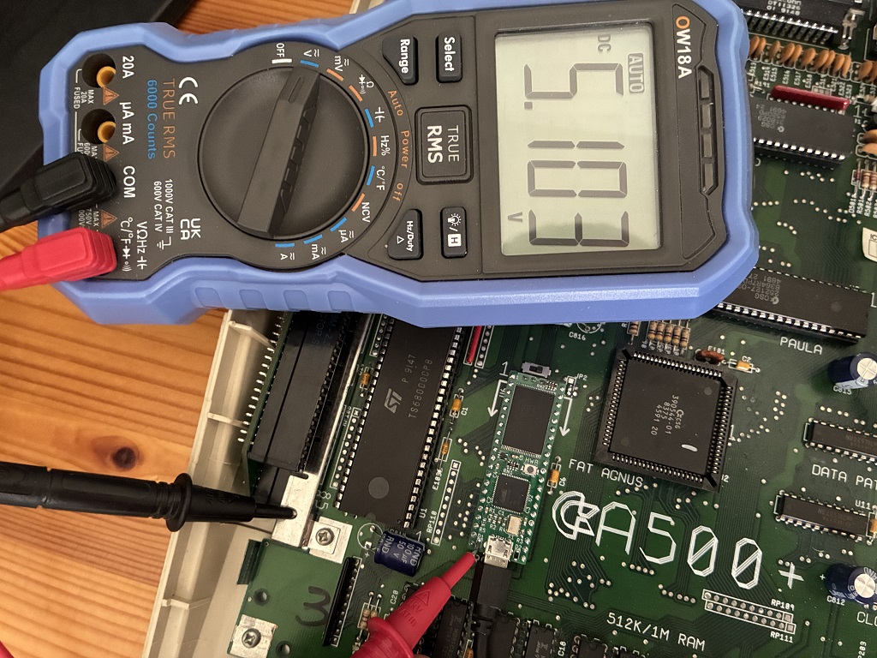
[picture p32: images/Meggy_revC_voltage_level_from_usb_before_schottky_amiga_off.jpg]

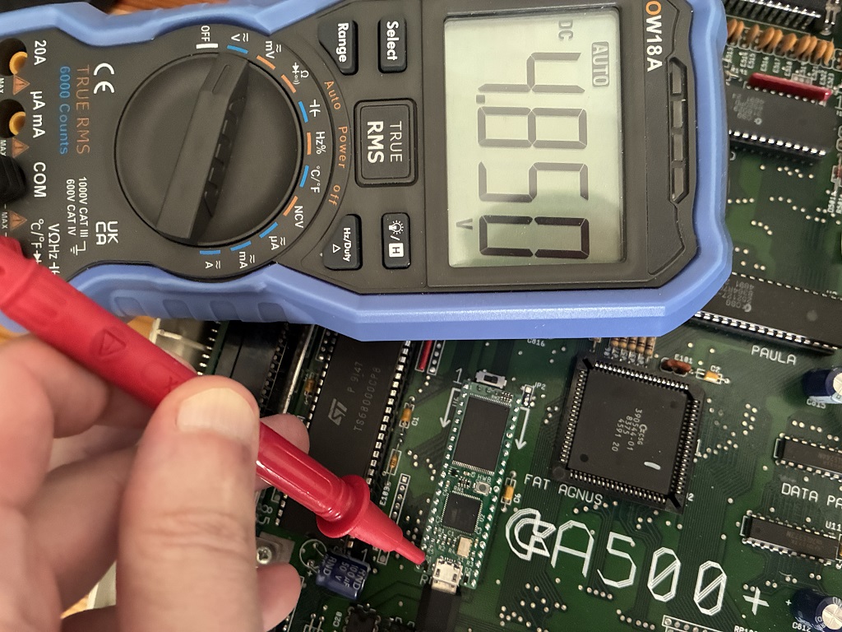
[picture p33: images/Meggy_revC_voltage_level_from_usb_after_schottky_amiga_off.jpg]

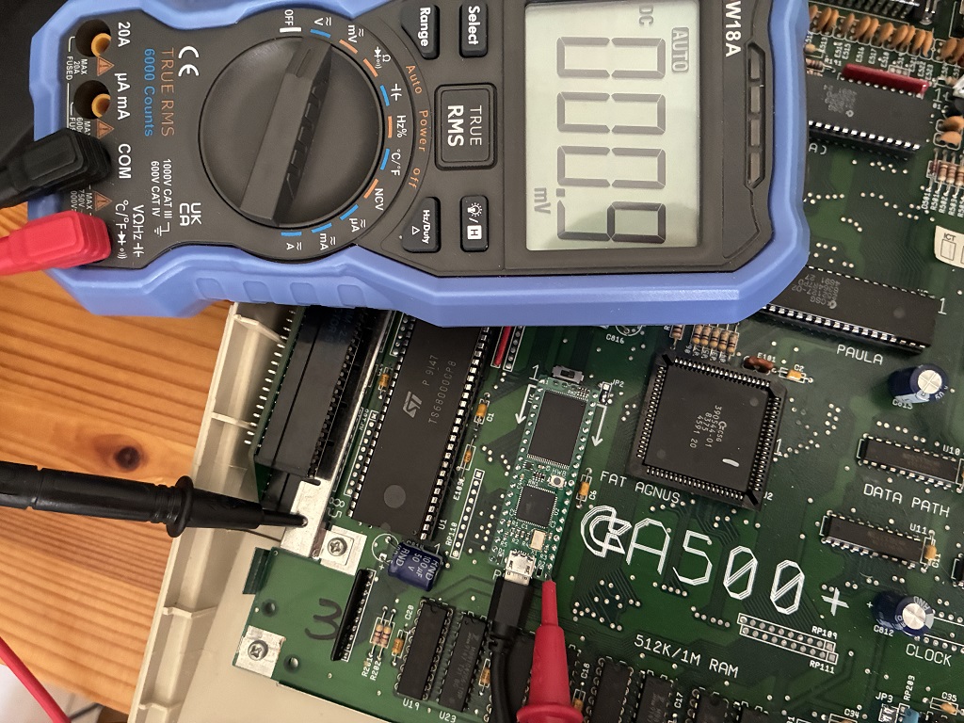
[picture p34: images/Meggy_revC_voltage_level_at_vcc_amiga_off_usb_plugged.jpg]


Left to right: **5.103V** raw USB VBUS before D2 — **4.85V** on BOARD_5V after D2 (~250mV Schottky drop) — **0.9mV** on Amiga VCC rail, effectively zero. D1 correctly blocks backfeed from BOARD_5V into the unpowered Amiga.

**Amiga powered on — USB plugged and unplugged:**

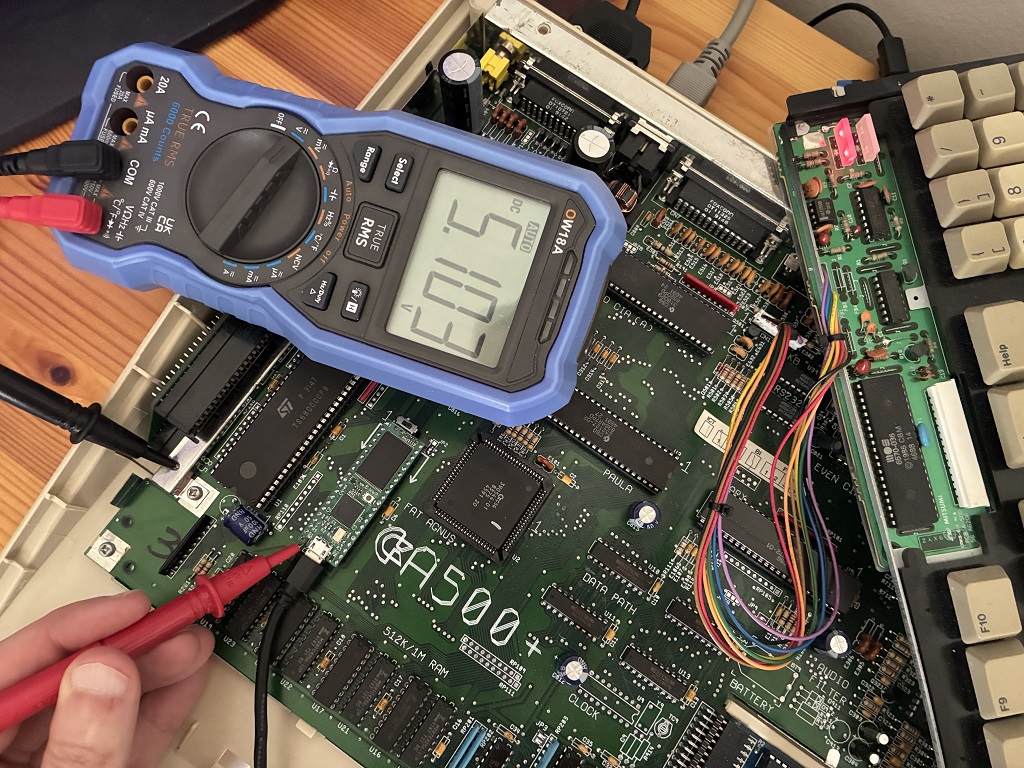
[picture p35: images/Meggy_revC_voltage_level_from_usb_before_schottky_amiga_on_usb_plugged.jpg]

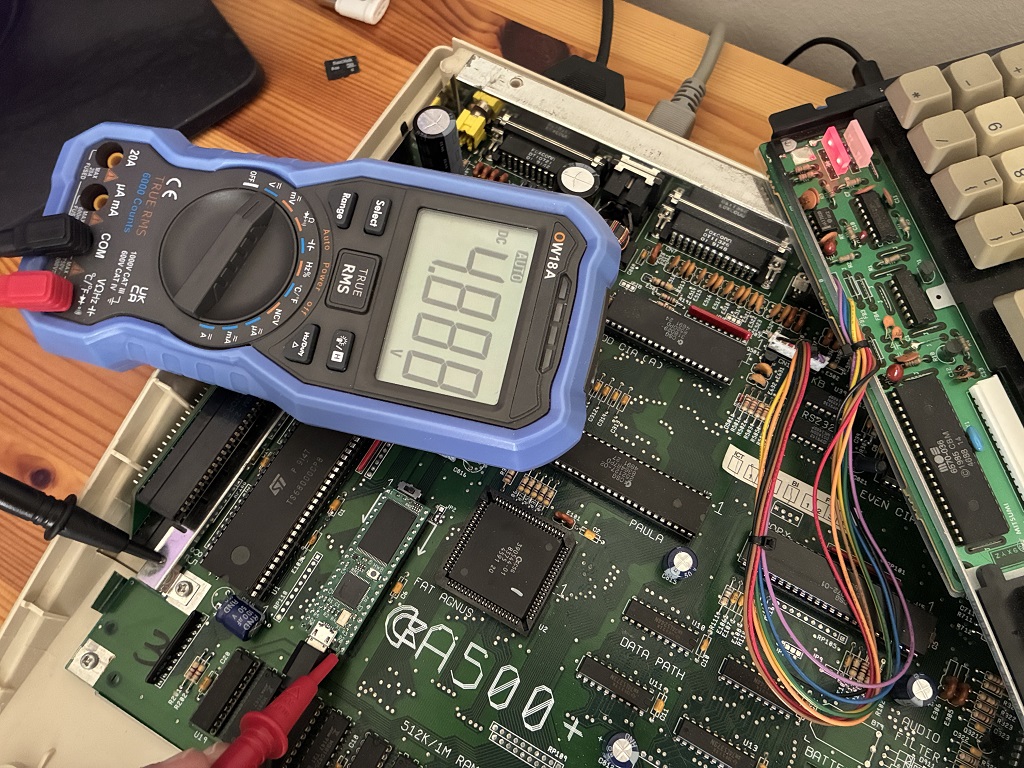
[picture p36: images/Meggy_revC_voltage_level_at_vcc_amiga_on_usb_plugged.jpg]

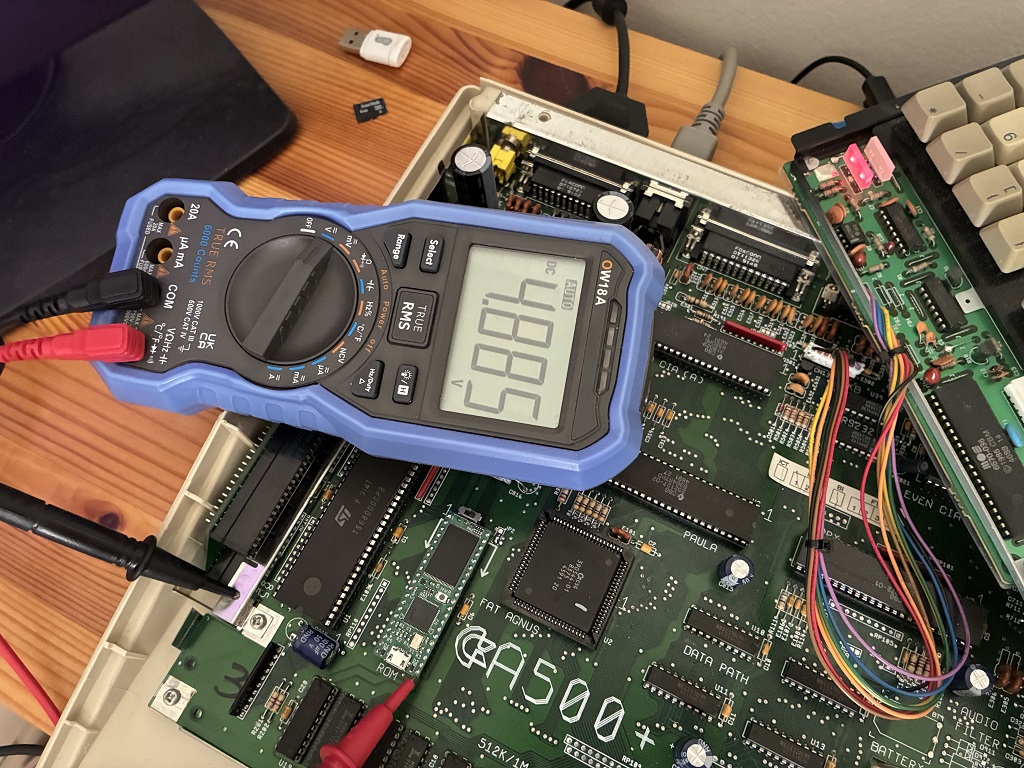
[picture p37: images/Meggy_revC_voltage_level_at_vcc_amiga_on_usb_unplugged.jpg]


Left to right: **5.103V** VBUS before Schottky with Amiga on and USB plugged — **4.888V** on BOARD_5V with Amiga on and USB plugged — **4.885V** on BOARD_5V with Amiga on and USB unplugged. The diode-OR selects the higher of the two supplies; with only Amiga VCC present the board runs stably at 4.885V.

***

# Image Slot Selection (J2)

J2 controls flash address line A19, selecting which of the two 1MB Kickstart image slots is visible to the Amiga at boot. The switch position also determines which slot is programmed when using `meggy_flash.py`.

| J2 position | Flash A19 | Slot | Typical use |
|---|---|---|---|
| Open | High (10k pull-up) | Slot 1 | Second image |
| Shorted to GND | Low | Slot 0 | Primary / default image |

The switch can be either the MSK12D19 SMD slide switch specified in the BOM (pins bent to right-angle for flush mounting) or a 3-pin 2.54 mm right-angle pin header fitted with an external toggle or jumper.

To change Kickstart without opening the Amiga, route a short cable from J2 to a switch mounted in a convenient location on the machine.

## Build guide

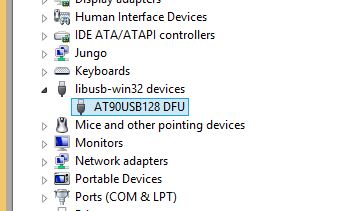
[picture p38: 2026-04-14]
images/Install_Zadig_pic5.jpg

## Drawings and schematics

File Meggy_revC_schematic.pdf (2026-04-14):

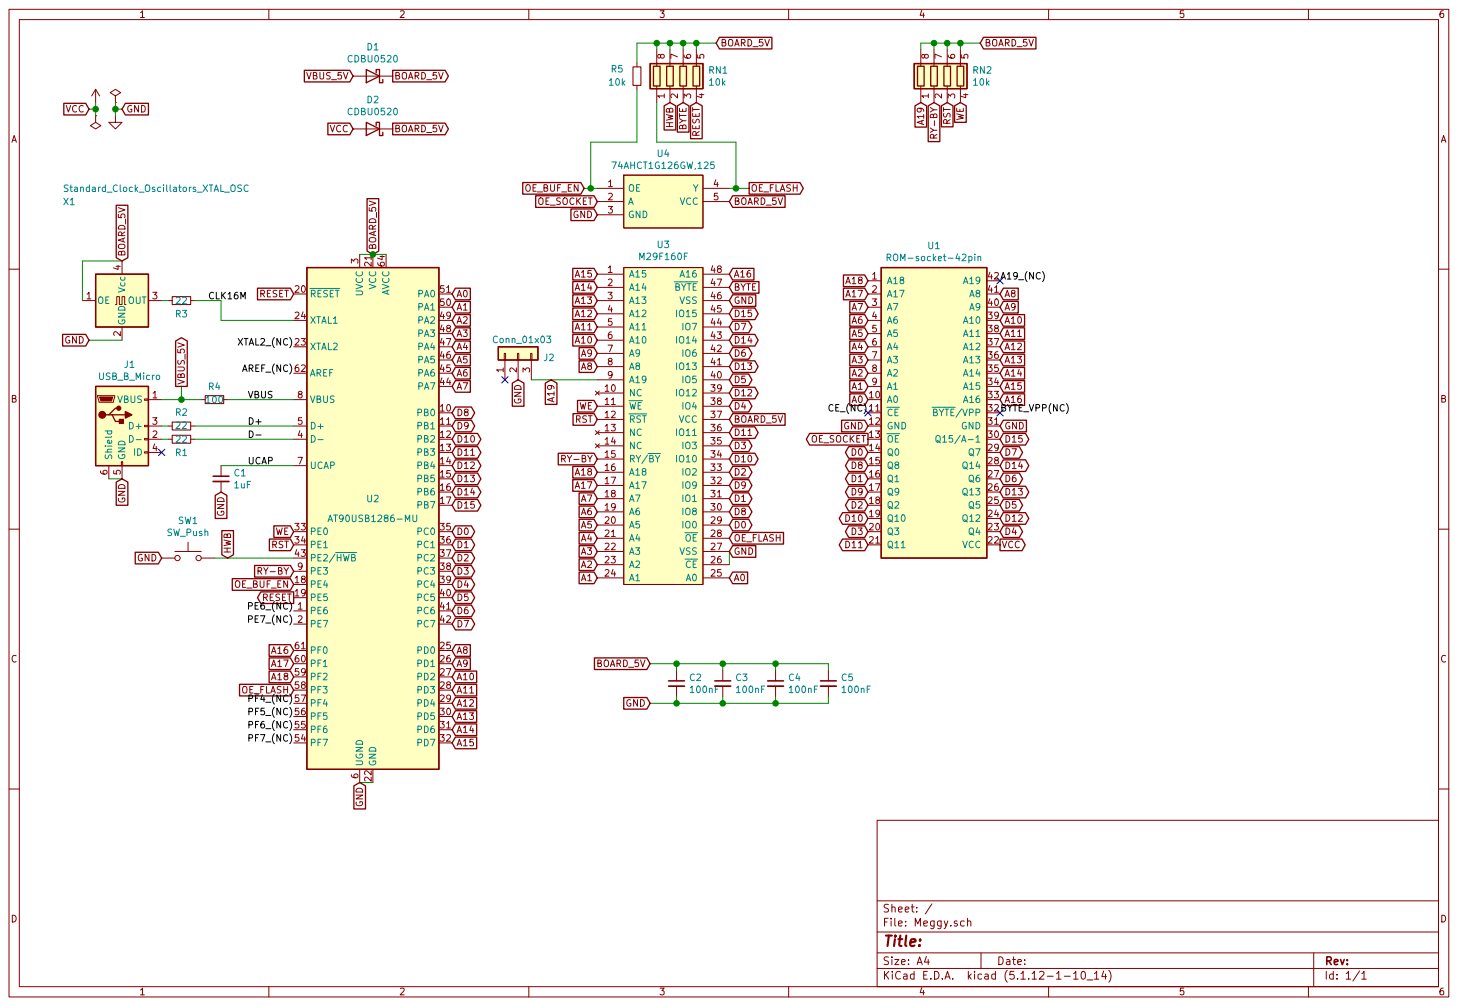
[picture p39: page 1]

CE_(NC) VBUS D- UCAP D+PF4_(NC)

File: Meggy.sch Sheet: /

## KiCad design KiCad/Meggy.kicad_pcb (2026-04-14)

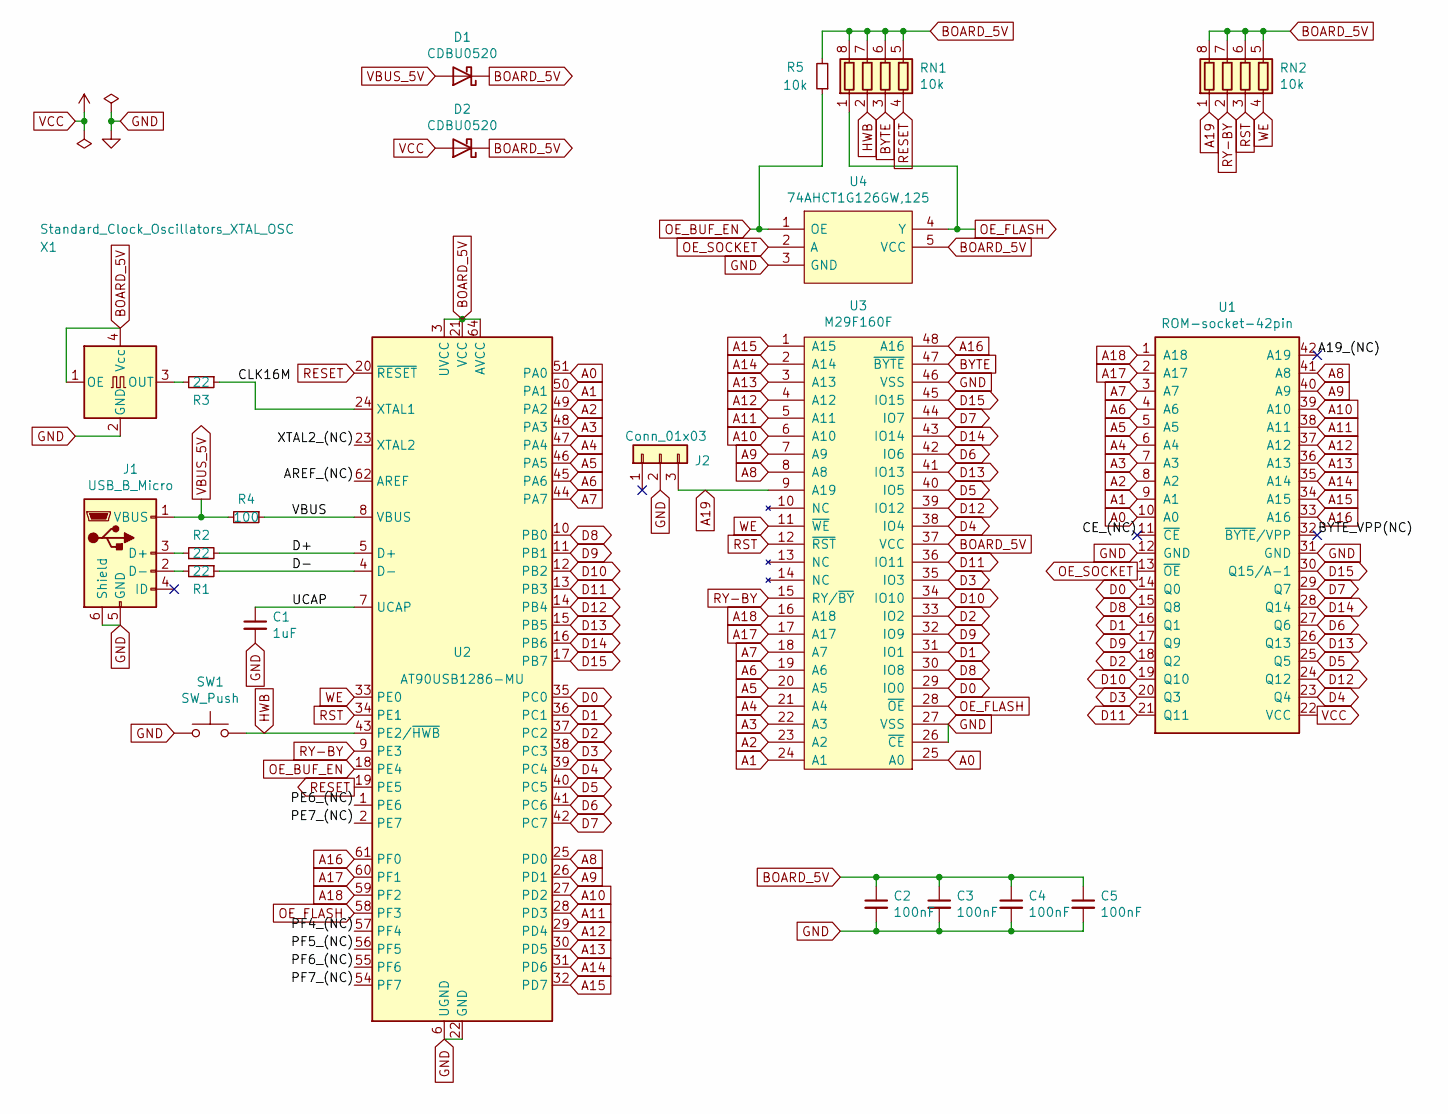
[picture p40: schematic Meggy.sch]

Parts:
C1: 1uF; C_0603_1608Metric_Pad1.08x0.95mm_HandSolder
C2, C3, C4, C5: 100nF; C_0603_1608Metric_Pad1.08x0.95mm_HandSolder
D1, D2: CDBU0520; D_0603_1608Metric_Pad_0.975x0.95mm_HandSolder
J1: USB_B_Micro; 101181940001LF
J2: Conn_01x03; PinHeader_1x03_P2.54mm_Vertical
R1, R2: 22; R_0603_1608Metric_Pad0.98x0.95mm_HandSolder
R3: 22; R_0603_1608Metric
R4: 100; R_0603_1608Metric_Pad0.98x0.95mm_HandSolder
R5: 10k; R_0603_1608Metric
RN1, RN2: 10k; RESCAF80P320X160X60-8N
SW1: SW_Push; Sunrom_Tactile_Switch_3x4x2mm_SMD_2-Pin
U1: ROM-socket-42pin; DIP-42_W15.24mm
U2: AT90USB1286-MU; QFN50P900X900X100-65N-D
U3: M29F160F; TSOP-I-48_18.4x12mm_P0.5mm
U4: 74AHCT1G126GW,125; SOT-353_SC-70-5
X1: Standard_Clock_Oscillators_XTAL_OSC; Oscillator_SMD_SeikoEpson_SG8002LB-4Pin_5.0x3.2mm

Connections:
/A19_(NC): U1.42 (A19)
/AREF_(NC): U2.62 (AREF)
/BYTE_VPP(NC): U1.32 (~BYTE~/VPP)
/CE_(NC): U1.11 (~CE)
/CLK16M: R3.1, U2.24 (XTAL1)
/D+: R2.2, U2.5 (D+)
/D-: R1.1, U2.4 (D-)
/PE6_(NC): U2.1 (PE6)
/PE7_(NC): U2.2 (PE7)
/PF4_(NC): U2.57 (PF4)
/PF5_(NC): U2.56 (PF5)
/PF6_(NC): U2.55 (PF6)
/PF7_(NC): U2.54 (PF7)
/UCAP: C1.1, U2.7 (UCAP)
/VBUS: R4.1, U2.8 (VBUS)
/XTAL2_(NC): U2.23 (XTAL2)
A0: U1.10 (A0), U2.51 (PA0), U3.25 (A0)
A1: U1.9 (A1), U2.50 (PA1), U3.24 (A1)
A2: U1.8 (A2), U2.49 (PA2), U3.23 (A2)
A3: U1.7 (A3), U2.48 (PA3), U3.22 (A3)
A4: U1.6 (A4), U2.47 (PA4), U3.21 (A4)
A5: U1.5 (A5), U2.46 (PA5), U3.20 (A5)
A6: U1.4 (A6), U2.45 (PA6), U3.19 (A6)
A7: U1.3 (A7), U2.44 (PA7), U3.18 (A7)
A8: U1.41 (A8), U2.25 (PD0), U3.8 (A8)
A9: U1.40 (A9), U2.26 (PD1), U3.7 (A9)
A10: U1.39 (A10), U2.27 (PD2), U3.6 (A10)
A11: U1.38 (A11), U2.28 (PD3), U3.5 (A11)
A12: U1.37 (A12), U2.29 (PD4), U3.4 (A12)
A13: U1.36 (A13), U2.30 (PD5), U3.3 (A13)
A14: U1.35 (A14), U2.31 (PD6), U3.2 (A14)
A15: U1.34 (A15), U2.32 (PD7), U3.1 (A15)
A16: U1.33 (A16), U2.61 (PF0), U3.48 (A16)
A17: U1.2 (A17), U2.60 (PF1), U3.17 (A17)
A18: U1.1 (A18), U2.59 (PF2), U3.16 (A18)
A19: J2.3, RN2.1 (R1.1), U3.9 (A19)
BOARD_5V: C2.1, C3.1, C4.1, C5.1, D1.1 (K), D2.1 (K), R5.2, RN1.5 (R4.2), RN1.6 (R3.2), RN1.7 (R2.2), RN1.8 (R1.2), RN2.5 (R4.2), RN2.6 (R3.2), RN2.7 (R2.2), RN2.8 (R1.2), U2.3 (UVCC), U2.21 (VCC), U2.52 (VCC), U2.64 (AVCC), U3.37 (VCC), U4.5 (VCC), X1.1 (OE), X1.4 (Vcc)
BYTE: RN1.3 (R3.1), U3.47 (~BYTE)
D0: U1.14 (Q0), U2.35 (PC0), U3.29 (IO0)
D1: U1.16 (Q1), U2.36 (PC1), U3.31 (IO1)
D2: U1.18 (Q2), U2.37 (PC2), U3.33 (IO2)
D3: U1.20 (Q3), U2.38 (PC3), U3.35 (IO3)
D4: U1.23 (Q4), U2.39 (PC4), U3.38 (IO4)
D5: U1.25 (Q5), U2.40 (PC5), U3.40 (IO5)
D6: U1.27 (Q6), U2.41 (PC6), U3.42 (IO6)
D7: U1.29 (Q7), U2.42 (PC7), U3.44 (IO7)
D8: U1.15 (Q8), U2.10 (PB0), U3.30 (IO8)
D9: U1.17 (Q9), U2.11 (PB1), U3.32 (IO9)
D10: U1.19 (Q10), U2.12 (PB2), U3.34 (IO10)
D11: U1.21 (Q11), U2.13 (PB3), U3.36 (IO11)
D12: U1.24 (Q12), U2.14 (PB4), U3.39 (IO12)
D13: U1.26 (Q13), U2.15 (PB5), U3.41 (IO13)
D14: U1.28 (Q14), U2.16 (PB6), U3.43 (IO14)
D15: U1.30 (Q15/A-1), U2.17 (PB7), U3.45 (IO15)
GND: C1.2, C2.2, C3.2, C4.2, C5.2, J1.5 (GND), J1.6 (Shield), J2.2, SW1.1, U1.12 (GND), U1.31 (GND), U2.6 (UGND), U2.22 (GND), U2.53 (GND), U2.63 (GND), U2.65 (GND), U3.26 (~CE), U3.27 (VSS), U3.46 (VSS), U4.3 (GND), X1.2 (GND)
HWB: RN1.2 (R2.1), SW1.2, U2.43 (PE2/~HWB)
unnamed: J1.2 (D-), R1.2
unnamed: J1.3 (D+), R2.1
unnamed: R3.2, X1.3 (OUT)
OE_BUF_EN: R5.1, U2.18 (PE4), U4.1 (OE)
OE_FLASH: RN1.1 (R1.1), U2.58 (PF3), U3.28 (~OE), U4.4 (Y)
OE_SOCKET: U1.13 (~OE), U4.2 (A)
RESET: RN1.4 (R4.1), U2.19 (PE5), U2.20 (~RESET)
RST: RN2.3 (R3.1), U2.34 (PE1), U3.12 (~RST)
RY-BY: RN2.2 (R2.1), U2.9 (PE3), U3.15 (RY/~BY)
VBUS_5V: D1.2 (A), J1.1 (VBUS), R4.2
VCC: D2.2 (A), U1.22 (VCC)
WE: RN2.4 (R4.1), U2.33 (PE0), U3.11 (~WE)

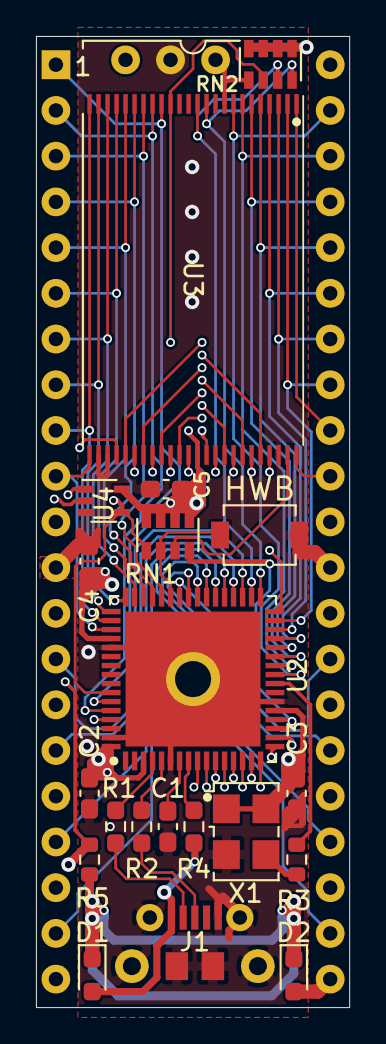
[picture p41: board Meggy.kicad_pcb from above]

Board: 4 copper layers, 17.4 x 54.0 mm, 22 parts (0 on the bottom side), 57 nets.

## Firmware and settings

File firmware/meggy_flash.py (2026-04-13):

#!/usr/bin/env python3
"""
meggy_flash.py — PC-side flash programmer for the Meggy ROM board.
Communicates with the AT90USB1286 firmware over USB (WinUSB via Zadig,
or native HID/libusb on Linux/macOS).

Requirements:
    pip install pyusb
    Windows: install WinUSB driver via Zadig for "Meggy Flash Programmer"
    Linux:   may need  sudo apt install libusb-1.0-0
             and a udev rule — see bottom of this file

Usage examples:
    python meggy_flash.py --identify
    python meggy_flash.py --read dump.bin
    python meggy_flash.py --write kickstart.bin --swap
    python meggy_flash.py --write diagrom.bin   --swap
    python meggy_flash.py --verify kickstart.bin --swap
    python meggy_flash.py --erase
"""

import argparse
import os
import sys
import time

try:
    import usb.core
    import usb.util
except ImportError:
    print("ERROR: pyusb not found.  Install with:  pip install pyusb")
    print("       Windows: also install WinUSB driver via Zadig.")
    sys.exit(1)

# ---------------------------------------------------------------------------
# USB device identity — must match Descriptors.c
# ---------------------------------------------------------------------------
USB_VID = 0x03EB
USB_PID = 0x2044

# Endpoint addresses — must match Descriptors.c
EP_TX   = 0x83   # IN  endpoint (device → host), address 3
EP_RX   = 0x04   # OUT endpoint (host → device), address 4
EP_SIZE = 64     # max packet size

# ---------------------------------------------------------------------------
# Protocol constants — must match firmware protocol.h
# ---------------------------------------------------------------------------
MAGIC            = b'\x4D\x47'

CMD_IDENTIFY     = 0x01
CMD_READ         = 0x02
CMD_CHIP_ERASE   = 0x03
CMD_SECTOR_ERASE = 0x04
CMD_PROGRAM      = 0x05
CMD_GET_STATUS   = 0x06
CMD_FLASH_RESET  = 0x07
CMD_AVR_RESET    = 0x08

STATUS_OK        = 0x00
STATUS_ERROR     = 0x01
STATUS_BUSY      = 0x02
STATUS_CRC_ERROR = 0x03
STATUS_TIMEOUT   = 0x04

STATUS_NAMES = {
    STATUS_OK:        "OK",
    STATUS_ERROR:     "ERROR",
    STATUS_BUSY:      "BUSY",
    STATUS_CRC_ERROR: "CRC_ERROR",
    STATUS_TIMEOUT:   "TIMEOUT",
}

CHUNK_WORDS  = 256
FLASH_WORDS  = 0x100000
FLASH_BYTES  = 0x200000
SLOT_WORDS   = 0x080000
SLOT_BYTES   = 0x100000

EXPECTED_MFR = 0x0020   # ST Microelectronics
EXPECTED_MFR2 = 0x0001  # Micron (also valid for M29F160FT)
EXPECTED_DEV = 0x22D2

# M29F160FT sector map: (start_word_addr, size_words)
# M29F160FT sector maps in AVR address space (0x000000-0x07FFFF).
# A19 is the hardware switch — the firmware always uses this range.
# Slot 0 (A19=0): 16 uniform 64KB sectors (lower half of flash)
SECTOR_MAP_SLOT0 = [(i * 0x8000, 0x8000) for i in range(16)]
# Slot 1 (A19=1): 15 uniform 64KB + top-boot block (upper half of flash)
SECTOR_MAP_SLOT1 = (
    [(i * 0x8000, 0x8000) for i in range(15)] +
    [(0x78000, 0x4000),
     (0x7C000, 0x1000),
     (0x7D000, 0x1000),
     (0x7E000, 0x2000)]
)
SECTOR_MAP = SECTOR_MAP_SLOT0  # default

# ---------------------------------------------------------------------------
# CRC-16/CCITT-FALSE
# ---------------------------------------------------------------------------
def crc16(data: bytes) -> int:
    crc = 0xFFFF
    for byte in data:
        crc ^= byte << 8
        for _ in range(8):
            crc = ((crc << 1) ^ 0x1021) if (crc & 0x8000) else (crc << 1)
            crc &= 0xFFFF
    return crc

# ---------------------------------------------------------------------------
# Byte-swap: swap bytes within each 16-bit word
# ---------------------------------------------------------------------------
def byteswap_words(data: bytes) -> bytes:
    if len(data) % 2:
        raise ValueError("Data length must be even for 16-bit byte swap")
    arr = bytearray(len(data))
    for i in range(0, len(data), 2):
        arr[i]   = data[i + 1]
        arr[i+1] = data[i]
    return bytes(arr)

# ---------------------------------------------------------------------------
# Progress bar
# ---------------------------------------------------------------------------
def _progress(done: int, total: int) -> None:
    pct = done * 100 // total
    bar = '#' * (pct // 2) + '-' * (50 - pct // 2)
    print(f"\r  [{bar}] {pct:3d}%  {done:,}/{total:,} bytes",
          end='', flush=True)

# ---------------------------------------------------------------------------
# MeggyCom — USB transport layer using pyusb
# ---------------------------------------------------------------------------
class MeggyCom:
    def __init__(self):
        dev = usb.core.find(idVendor=USB_VID, idProduct=USB_PID)
        if dev is None:
            raise RuntimeError(
                "Meggy device not found.\n"
                "  - Is the firmware running (not in DFU mode)?\n"
                "  - Is the USB cable connected?\n"
                "  - Windows: has the WinUSB driver been installed via Zadig?"
            )

        # Detach kernel driver on Linux if needed
        if sys.platform != "win32":
            for iface in [0, 1]:
                try:
                    if dev.is_kernel_driver_active(iface):
                        dev.detach_kernel_driver(iface)
                except Exception:
                    pass

        dev.set_configuration()
        self.dev = dev

        # Internal receive buffer — holds leftover bytes from USB packets
        # that were larger than what _usb_read() requested at that moment.
        self._rxbuf = bytearray()

        # Flush any stale data sitting in the IN endpoint buffer
        try:
            while True:
                self.dev.read(EP_TX, EP_SIZE, timeout=50)
        except usb.core.USBTimeoutError:
            pass
        except usb.core.USBError:
            pass

    def close(self):
        usb.util.dispose_resources(self.dev)

    # -----------------------------------------------------------------------
    # Raw USB write — splits into EP_SIZE chunks automatically
    # -----------------------------------------------------------------------
    def _usb_write(self, data: bytes) -> None:
        offset = 0
        while offset < len(data):
            chunk = data[offset: offset + EP_SIZE]
            self.dev.write(EP_RX, chunk, timeout=2000)
            offset += len(chunk)

    # -----------------------------------------------------------------------
    # Raw USB read — returns exactly 'count' bytes.
    # Buffers any extra bytes received in a USB packet so they are
    # available for the next call instead of being discarded.
    # This is essential because pyusb returns full USB packets at once
    # even when we only ask for part of the data.
    # -----------------------------------------------------------------------
    def _usb_read(self, count: int, timeout_ms: int = 5000) -> bytes:
        deadline = time.time() + timeout_ms / 1000.0

        while len(self._rxbuf) < count:
            if time.time() > deadline:
                raise TimeoutError(
                    f"USB read timeout: got {len(self._rxbuf)}/{count} bytes"
                )
            remaining_ms = int((deadline - time.time()) * 1000)
            if remaining_ms <= 0:
                raise TimeoutError(
                    f"USB read timeout: got {len(self._rxbuf)}/{count} bytes"
                )
            try:
                # Read one USB packet — may be up to EP_SIZE bytes.
                # All bytes go into the buffer; we return exactly 'count'.
                packet = self.dev.read(EP_TX, EP_SIZE,
                                       timeout=min(remaining_ms, 500))
                self._rxbuf.extend(bytes(packet))
            except usb.core.USBTimeoutError:
                if time.time() >= deadline:
                    raise TimeoutError(
                        f"USB read timeout: got {len(self._rxbuf)}/{count} bytes"
                    )

        # Return exactly count bytes, leave the rest in the buffer
        result       = bytes(self._rxbuf[:count])
        self._rxbuf  = self._rxbuf[count:]
        return result

    # -----------------------------------------------------------------------
    # Packet builder — same format as before
    # -----------------------------------------------------------------------
    def _build_packet(self, cmd: int, addr: int,
                      length_words: int, payload: bytes = b'') -> bytes:
        header = bytes([
            MAGIC[0], MAGIC[1],
            cmd,
            (addr         >> 16) & 0xFF,
            (addr         >>  8) & 0xFF,
             addr                & 0xFF,
            (length_words >>  8) & 0xFF,
             length_words        & 0xFF,
        ])
        body     = header + payload
        checksum = crc16(body)
        return body + bytes([checksum >> 8, checksum & 0xFF])

    # -----------------------------------------------------------------------
    # Receive and validate one response packet
    # -----------------------------------------------------------------------
    def _recv_response(self) -> tuple:
        header = self._usb_read(5)
        if header[0:2] != MAGIC:
            raise ValueError(f"Bad magic in response: {header[0:2].hex()}")

        status       = header[2]
        length_words = (header[3] << 8) | header[4]
        data_bytes   = length_words * 2

        rest = self._usb_read(data_bytes + 2) if (data_bytes + 2) > 0 \
               else self._usb_read(2)

        payload  = rest[:data_bytes]
        crc_got  = (rest[-2] << 8) | rest[-1]
        crc_calc = crc16(bytes(header) + bytes(rest[:-2]))

        if crc_got != crc_calc:
            raise ValueError(
                f"CRC mismatch: got 0x{crc_got:04X} expected 0x{crc_calc:04X}"
            )
        return status, bytes(payload)

    # -----------------------------------------------------------------------
    # Send + receive with retries
    # -----------------------------------------------------------------------
    def _transact(self, cmd: int, addr: int = 0,
                  length_words: int = 0, payload: bytes = b'',
                  retries: int = 3) -> tuple:
        last_exc = None
        for attempt in range(retries):
            try:
                pkt = self._build_packet(cmd, addr, length_words, payload)
                self._usb_write(pkt)
                return self._recv_response()
            except (TimeoutError, ValueError, usb.core.USBError) as e:
                last_exc = e
                # Flush stale data and clear internal buffer before retry
                self._rxbuf.clear()
                try:
                    while True:
                        self.dev.read(EP_TX, EP_SIZE, timeout=50)
                except Exception:
                    pass
                time.sleep(0.15 * (attempt + 1))
        raise last_exc

    # -----------------------------------------------------------------------
    # Flash operations
    # -----------------------------------------------------------------------

    def identify(self) -> tuple:
        status, data = self._transact(CMD_IDENTIFY)
        if status != STATUS_OK or len(data) < 4:
            raise RuntimeError(
                f"IDENTIFY failed: {STATUS_NAMES.get(status, hex(status))}"
            )
        # AVR stores uint16_t little-endian (low byte first).
        # Parse accordingly — big-endian interpretation gives wrong values.
        mfr = data[0] | (data[1] << 8)
        dev = data[2] | (data[3] << 8)
        return mfr, dev

    def flash_reset(self, verbose: bool = False) -> None:
        status, data = self._transact(CMD_FLASH_RESET)
        if status != STATUS_OK:
            raise RuntimeError("FLASH_RESET failed")
        if verbose and len(data) >= 4:
            w0 = data[0] | (data[1] << 8)
            w1 = data[2] | (data[3] << 8)
            print(f"  Flash reset: word[0]=0x{w0:04X} word[1]=0x{w1:04X}")
            # Autoselect responses have 0x21 in the high byte (ST/Micron)
            # or 0x01 in the high byte — any 0x21xx value is autoselect
            if (w0 >> 8) == 0x21 or (w0 >> 8) == 0x01 or w0 == w1:
                print(f"  WARNING: Flash still in autoselect/error state! (0x{w0:04X})")
                print(f"  Try power cycling the Meggy board (unplug USB, wait, replug).")
            else:
                print(f"  Flash is in read mode.")

    def get_status(self) -> int:
        status, _ = self._transact(CMD_GET_STATUS)
        return status

    def wait_ready(self, timeout_s: float = 220.0,
                   poll_interval: float = 0.5,
                   show_dots: bool = True) -> None:
        deadline = time.time() + timeout_s
        dots = 0
        while time.time() < deadline:
            s = self.get_status()
            if s == STATUS_OK:
                if show_dots and dots:
                    print()
                return
            if s != STATUS_BUSY:
                raise RuntimeError(
                    f"Unexpected status: {STATUS_NAMES.get(s, hex(s))}"
                )
            if show_dots:
                print(".", end="", flush=True)
                dots += 1
            time.sleep(poll_interval)
        raise TimeoutError("Flash did not become ready within timeout")

    def chip_erase(self) -> None:
        status, _ = self._transact(CMD_CHIP_ERASE)
        if status not in (STATUS_OK, STATUS_BUSY):
            raise RuntimeError(
                f"CHIP_ERASE failed: {STATUS_NAMES.get(status, hex(status))}"
            )

    def sector_erase(self, word_addr: int) -> None:
        status, _ = self._transact(CMD_SECTOR_ERASE, addr=word_addr)
        if status not in (STATUS_OK, STATUS_BUSY):
            raise RuntimeError(
                f"SECTOR_ERASE failed at 0x{word_addr:06X}: "
                f"{STATUS_NAMES.get(status, hex(status))}"
            )

    def read(self, word_addr: int, word_count: int,
             show_progress: bool = True) -> bytes:
        # Always reset flash to read mode before any read operation.
        # This ensures we are not reading autoselect/status data if
        # the flash was left in a non-read state by a previous command.
        self.flash_reset()

        result       = bytearray()
        words_left   = word_count
        current_addr = word_addr
        total_bytes  = word_count * 2

        if show_progress:
            print(f"Reading {total_bytes:,} bytes...")

        while words_left > 0:
            chunk = min(words_left, CHUNK_WORDS)
            status, data = self._transact(
                CMD_READ,
                addr=current_addr,
                length_words=chunk,
                retries=5,
            )
            if status != STATUS_OK:
                raise RuntimeError(
                    f"READ failed at 0x{current_addr:06X}: "
                    f"{STATUS_NAMES.get(status, hex(status))}"
                )
            if len(data) != chunk * 2:
                raise RuntimeError(
                    f"READ: got {len(data)} bytes, expected {chunk * 2}"
                )
            result.extend(data)
            current_addr += chunk
            words_left   -= chunk
            if show_progress:
                _progress(len(result), total_bytes)

        if show_progress:
            print()
        return bytes(result)

    def program(self, word_addr: int, data: bytes,
                show_progress: bool = True) -> None:
        if len(data) % 2:
            raise ValueError("Data length must be even")

        total_bytes  = len(data)
        words_left   = total_bytes // 2
        current_addr = word_addr
        offset       = 0

        if show_progress:
            print(f"Programming {total_bytes:,} bytes...")

        while words_left > 0:
            chunk_w = min(words_left, CHUNK_WORDS)
            chunk_b = chunk_w * 2
            payload = data[offset: offset + chunk_b]
            status, _ = self._transact(
                CMD_PROGRAM,
                addr=current_addr,
                length_words=chunk_w,
                payload=payload,
            )
            if status != STATUS_OK:
                raise RuntimeError(
                    f"PROGRAM failed at 0x{current_addr:06X}: "
                    f"{STATUS_NAMES.get(status, hex(status))}"
                )
            current_addr += chunk_w
            words_left   -= chunk_w
            offset       += chunk_b
            if show_progress:
                _progress(offset, total_bytes)

        if show_progress:
            print()

    def verify(self, word_addr: int, expected: bytes,
               show_progress: bool = True) -> bool:
        if show_progress:
            print("Verifying...")
        actual = self.read(word_addr, len(expected) // 2,
                           show_progress=show_progress)
        if actual == expected:
            if show_progress:
                print("Verify OK.")
            return True
        for i, (a, b) in enumerate(zip(actual, expected)):
            if a != b:
                wa = word_addr + i // 2
                print(f"\nVERIFY FAILED byte 0x{i:06X} "
                      f"(word 0x{wa:06X}): "
                      f"read 0x{a:02X} expected 0x{b:02X}")
                break
        return False


# ---------------------------------------------------------------------------
# Helpers
# ---------------------------------------------------------------------------
def erase_chip(dev: MeggyCom) -> None:
    print("Erasing entire chip (~30 seconds)...")
    print("  (A19 switch position does not matter for chip erase)")
    dev.chip_erase()
    dev.wait_ready(timeout_s=220)
    dev.flash_reset()
    print("Chip erase complete.")

def erase_current_slot(dev: MeggyCom) -> None:
    # A19 switch selects the physical slot — firmware always uses 0x000000-0x07FFFF.
    # Use SECTOR_MAP_SLOT1 (19 sectors including top-boot) to cover all cases.
    # If A19=low (slot 0), the top-boot sectors still exist at those addresses.
    secs = SECTOR_MAP_SLOT1
    print(f"Erasing {len(secs)} sectors...")
    print(f"  (set A19 switch to desired slot before erasing)")
    for i, (s_addr, s_size) in enumerate(secs):
        print(f"  Sector {i+1}/{len(secs)} addr=0x{s_addr:06X}...", end='', flush=True)
        dev.sector_erase(s_addr)
        dev.wait_ready(timeout_s=30, show_dots=False)
        dev.flash_reset()
        check = dev.read(s_addr, 1, show_progress=False)
        word = check[0] | (check[1] << 8)
        if word == 0xFFFF:
            print(" blank OK")
        else:
            print(f" WARNING: 0x{word:04X} != 0xFFFF - NOT ERASED!")
    print(f"  All {len(secs)} sectors erased.")

def load_image(path: str, swap: bool) -> tuple:
    """Load a ROM image, byteswap if requested, pad to 1MB.
    Always returns word_addr=0 — the A19 switch selects the physical slot."""
    with open(path, "rb") as f:
        data = f.read()
    print(f"Loaded {len(data):,} bytes from {path}")
    if swap:
        data = byteswap_words(data)
        print("16-bit byte-swap applied.")
    if len(data) > SLOT_BYTES:
        print(f"ERROR: Image ({len(data):,} B) exceeds 1 MB slot ({SLOT_BYTES:,} B).")
        sys.exit(1)
    if len(data) < SLOT_BYTES:
        pad = SLOT_BYTES - len(data)
        print(f"Padding with 0xFF (+{pad:,} bytes).")
        data += b'\xFF' * pad
    return data, 0

# ---------------------------------------------------------------------------
# CLI
# ---------------------------------------------------------------------------
def parse_args():
    p = argparse.ArgumentParser(
        description="Meggy ROM board flash programmer (USB/WinUSB)",
        formatter_class=argparse.RawDescriptionHelpFormatter,
        epilog="""
Setup:
  Windows: install WinUSB driver for "Meggy Flash Programmer" via Zadig
  Linux:   pip install pyusb  (may also need a udev rule, see below)

Examples:
  python meggy_flash.py --identify
  python meggy_flash.py --read dump.bin
  python meggy_flash.py --erase
  python meggy_flash.py --write ks314_1mb.rom --swap
  python meggy_flash.py --write diagrom.bin   --swap
  python meggy_flash.py --verify ks314_1mb.rom --swap

Linux udev rule (create /etc/udev/rules.d/99-meggy.rules):
  SUBSYSTEM=="usb", ATTR{idVendor}=="03eb", ATTR{idProduct}=="2044", MODE="0666"
        """,
    )
    p.add_argument("--identify",  action="store_true",
                   help="Read flash manufacturer/device ID")
    p.add_argument("--read",   metavar="FILE",
                   help="Dump full 2 MB flash to FILE")
    p.add_argument("--read-slot", metavar="FILE",
                   help="Dump the currently selected 1 MB slot to FILE "
                        "(set A19 switch first, then run this)")
    p.add_argument("--write",  metavar="FILE",
                   help="Erase and program flash from FILE")
    p.add_argument("--verify", metavar="FILE",
                   help="Verify flash against FILE (no programming)")
    p.add_argument("--erase",  action="store_true",
                   help="Erase current slot (set A19 switch to desired slot first)")
    p.add_argument("--swap",   action="store_true",
                   help="16-bit byte-swap FILE before programming/verifying")
    p.add_argument("--reset",  action="store_true",
                   help="Send AMD reset command to flash")
    p.add_argument("--avr-reset", action="store_true",
                   help="Trigger AVR watchdog reset (reboots firmware)")
    p.add_argument("--selftest", action="store_true",
                   help="Write/read/verify a known pattern to sector 0 (diagnostic)")
    p.add_argument("--loopback", action="store_true",
                   help="Send a raw GET_STATUS command and print raw bytes (diagnostic)")
    return p.parse_args()
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

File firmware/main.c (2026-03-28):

#include <avr/io.h>
#include <avr/wdt.h>
#include <avr/power.h>
#include <avr/interrupt.h>

#include <LUFA/Drivers/USB/USB.h>

#include "Descriptors.h"
#include "flash.h"
#include "protocol.h"

int main(void)
{
    /* Disable watchdog left active by the DFU bootloader */
    MCUSR &= ~(1 << WDRF);
    wdt_disable();

    /* Full speed 16 MHz */
    clock_prescale_set(clock_div_1);

    /* Initialise flash I/O pins */
    flash_init();

    /* Start USB stack */
    USB_Init();

    /* Enable global interrupts */
    sei();

    for (;;) {
        protocol_task();
        USB_USBTask();
    }
}

void EVENT_USB_Device_Connect(void)    {}
void EVENT_USB_Device_Disconnect(void) {}

void EVENT_USB_Device_ConfigurationChanged(void)
{
    /* Configure the two bulk endpoints */
    Endpoint_ConfigureEndpoint(BULK_IN_EPADDR,  EP_TYPE_BULK,
                               BULK_EP_SIZE, 1);
    Endpoint_ConfigureEndpoint(BULK_OUT_EPADDR, EP_TYPE_BULK,
                               BULK_EP_SIZE, 1);
}

void EVENT_USB_Device_ControlRequest(void) {}

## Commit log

2025-09-17 Add KiCad files
    [Meggy.kicad_pcb, Meggy.sch]
2025-09-17 Add USB-Micro footprint for 10118194-0001LF
2025-09-17 Add 3D model of Micro USB connector 10118194-0001LF
2025-09-17 Add Micro USB connector and resistors R1-R3
    [Meggy.kicad_pcb, Meggy.sch]
2025-09-18 Add U3 M29F160F, pin assignment and preliminary routing
    [Meggy.kicad_pcb, Meggy.sch]
2025-09-19 Add capacitors and a XTAL_OSC plus 22 Ohm resistor for 16MHz clock and more placement and routing
    [Meggy.kicad_pcb, Meggy.sch]
2025-09-20 Add MOSFET DMP2305U-7 to library
2025-09-20 Added Q1 and Q2 MOSFETs, changed footprint on CLK16M resistor and routed RST and WE signals
    [Meggy.kicad_pcb, Meggy.sch]
2025-09-20 Add footprint
2025-09-20 Removed R5,R6 and added D1,D2 changing the 5V Power Protection & ORing Circuit
    [Meggy.kicad_pcb, Meggy.sch]
2025-09-21 Add circuit for controlling Flash-OE signal
    [Meggy.kicad_pcb, Meggy.sch]
2025-09-21 Add 10k pull-up resistor network for RY-BY, WE, RST and A19 signals
    [Meggy.kicad_pcb, Meggy.sch]
2025-09-21 Fix footprint for diode D3 and silkscreen fixes
    [Meggy.kicad_pcb, Meggy.sch]
2025-09-21 Add GND via stitching and some improved routing
    [Meggy.kicad_pcb, Meggy.sch]
2025-09-21 Change 3d model for X1
    [Meggy.kicad_pcb]
2025-09-21 Add push button for RESET and HWB lines
    [Meggy.kicad_pcb, Meggy.sch]
2025-09-21 Add 3D model for push buttons and fix names on pads not used (NC)
    [Meggy.kicad_pcb, Meggy.sch]
2025-09-22 Moving into 6-layer PCB design
    [Meggy.kicad_pcb, Meggy.sch]
2025-09-22 Re-routing improvements inner signal layer
    [Meggy.kicad_pcb]
2025-09-22 Re-routing improvements underside signal layer
    [Meggy.kicad_pcb]
2025-09-22 Re-routing improvements top side signal layer
    [Meggy.kicad_pcb]
2025-09-23 Add keep out copper pour area for USB pin 4
    [Meggy.kicad_pcb]
2025-09-23 Add silkscreen text and OSHW-symbol
    [Meggy.kicad_pcb]
2025-09-23 Add outputdirectory out/ for gerbers
    [Meggy.kicad_pcb]
2025-09-23 Switched back to 4-layer and did magic routing
    [Meggy.kicad_pcb]
2026-03-24 Remove Q3 and D3, replace with 74AHCT1G126GW and route OE_SOCKET_EN from pin PE4
    [Meggy.kicad_pcb, Meggy.sch]
2026-03-27 Optimize footprint hole sizes
2026-03-27 Fix pin assignments JTAG conflict, power OR circuit, OE isolation
    - Replace P-channel MOSFET power OR (Q1/Q2) with Schottky diodes
    - Replace Q3 MOSFET OE isolation with 74AHCT1G126GW tristate buffer (PE4 enable, 10k pull-up)
    - Move A16/A17/A18 from PF5/PF6/PF7 (JTAG conflict) to PF0/PF1/PF2
    - Move RY/BY from PF4 (JTAG conflict) to PE3
    [Meggy.kicad_pcb, Meggy.sch]
2026-03-27 Removed RESET-button
    [Meggy.kicad_pcb, Meggy.sch]
2026-03-28 Add CMD_AVR_RESET (watchdog), OE buffer isolation (PE4/74AHCT1G126GW), auto-reset in flash.bat
    - CMD_AVR_RESET (0x08): ACKs then triggers 15ms watchdog reset, bus/OE released first
    - oe_buf_isolate()/oe_buf_release(): PE4 controls 74AHCT1G126GW tristate during erase/program
    - flash.bat: calls --avr-reset after programming to auto-reboot into new firmware
    - meggy_flash.py: --avr-reset flag added
    [flash.c, meggy_flash.py, protocol.c]
2026-03-28 Update README with BOM
2026-04-13 Remove --image flag (A19 slot is hardware switch only), fix manufacturer ID 0x0001 recognised as valid Micron code
    [meggy_flash.py]
2026-04-13 Add PE5->RESET for DFU entry, fix flash.bat batch syntax errors
    - CMD_AVR_RESET now drives PE5 low to assert hardware RESET instead of watchdog
    - PE5 (pin 19) bridged to RESET (pin 20) on Rev B PCB, permanent trace in Rev C
    - flash.bat: fix parenthesis escaping causing premature if-block termination
    - flash.bat: remove -D flag, use temp file instead of pipe for reliable exit code
    - flash.bat: add power cycle instructions after successful flash
    - build.bat: update DFU entry instructions to reflect PE5 reset method
    [meggy_flash.py, protocol.c]
2026-04-14 Rev C: connect PE5 (pin 19) to /RESET (pin 20) for software DFU entry via --avr-reset
    [Meggy.kicad_pcb, Meggy.sch]
2026-04-14 Add schematic pdf
2026-04-14 Clean up code comments: remove Rev A/B bodge wire references, unused wdt.h include, fix manufacturer ID and PE5 reset description
    [flash.c, protocol.c]
2026-04-14 Replace SW1 with HWB button in build.bat and flash.bat output messages
2026-04-22 Add A500 rev 6A / 40-pin socket compatibility — modifications, installation photos and confirmed working with DiagROM and 1MB capitoline KS 3.1.4
2026-04-22 Add plastic guard orientation tip to pin headers assembly section

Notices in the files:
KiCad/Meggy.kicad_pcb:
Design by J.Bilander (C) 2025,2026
